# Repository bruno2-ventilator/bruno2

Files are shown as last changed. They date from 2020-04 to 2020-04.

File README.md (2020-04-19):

# BrunO2 Open Source Ventilator
This repository contains design information for a low cost ventilator designed by a team based at Brown University. We are a group of engineers, medical practitioners, and device designers developing a ventilator system based around custom proportional valves, MEMS pressure sensors, and closed-loop control system.

More details and videos are available on the [BrunO2 website](https://sites.brown.edu/bruno2/).

---
## License
These open source ventilator design materials are provided under the conditions specified in the [Permissive License](Permissive%20License--Brown%20University%20041720.pdf)

---
## Quick Links:
[System](Design%20Materials/System/)   /   [Mechanical](Design%20Materials/Mechanical/)   /   [Software](Design%20Materials/Software/)   /   [Electronics](Design%20Materials/Electronics/)   /   [BrunO2 website](https://sites.brown.edu/bruno2/).

---
## Getting Started:

COMING SOON

---
# Contributors to the BrunO2 project include:

**Brown University School of Engineering:**
- Prof. Dan Harris (Fluids)
- Prof. Roberto Zenit (Fluids)
- Prof. Kenny Breuer (Fluids)
- Prof. Jacob Rosenstein (ECE)
- Chris Bull (Director of BDW)
- Ben Lyons (BDW Staff)
- Garam Lee (MechE)
- Ian Ho (MechE)
- John Antolik (MechE)
- Will Haddock (MechE)
- Jacob Morse (MechE)
- Alberto Bortoni (ECE)
- Marc Powell (BME)
- Eli Silver (MechE)
- Chris Arcadia (ECE)

**Medical team and advisors:**
- Farah L Laiwalla MD/PhD, Prof, Brown BME
- Dan Dworkis, MD/PhD., Asst. Prof. Emergency Medicine, Keck School of Medicine of USC
- Gerardo P. Carino MD/PhD., Associate Professor of Medicine (Clinical), ICU Director, The Miriam Hospital
- Nicole Thomasian, Brown med student
- Roja Garimella, Brown med student
- Anastassia Gorvitovskaia, Brown med student

**Practicing Engineers:**
- Dave Durfee (Bay Computer Associates, Inc.)
- Andy Leonczyk (Ximedica)

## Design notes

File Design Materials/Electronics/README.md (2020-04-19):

# BrunO2 Ventilator Electronic Hardware Components

---
These open source ventilator design materials are provided under the conditions specified in the [Permissive License](../../Permissive%20License--Brown%20University%20041720.pdf)

---
# MORE DETAILS COMING SOON

---
# BrunO2 PCB v1
## 

[PDF Schematic](PCB_v1/BrunO2%20PCB%20Schematic%20v1.pdf)

[Eagle Schematic](PCB_v1/BrunO2_ControlBoard_v1.sch)

[Eagle Layout](PCB_v1/BrunO2_ControlBoard_v1.brd)

[Gerber Files](PCB_v1/BrunO2_ControlBoard_v1_Gerbers_2020-04-05.zip)

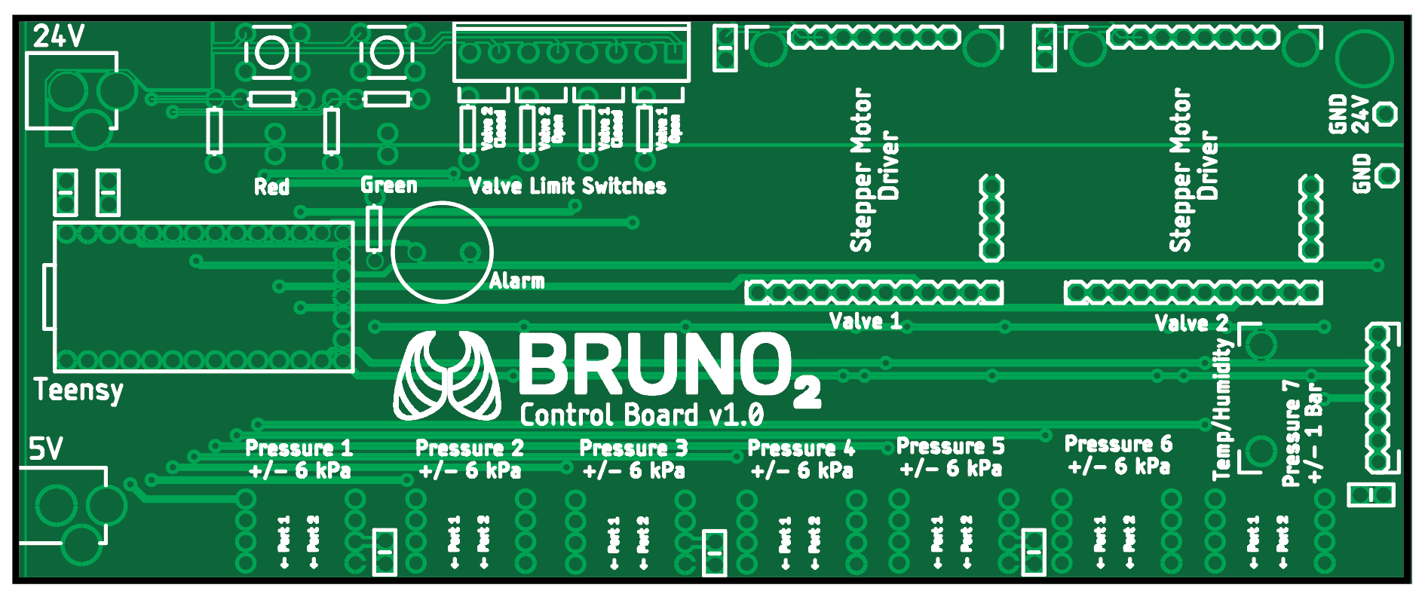
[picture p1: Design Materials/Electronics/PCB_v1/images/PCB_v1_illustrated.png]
PCB Illustration


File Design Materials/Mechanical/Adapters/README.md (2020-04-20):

# BrunO2 Cam Pinch Valve Design Materials

Please refer to [Adapter_Documentation.pdf](Adapter_Documentation.pdf)

This documents is a compilation of the 3D models of generic tube adapters and fittings we made for testing purposes. They were designed to be printed on a high resolution stereolithography 3D printer using biocompatible resin (Form Lab’s ‘Surgical Guide’ resin). All models included in this document have been shared in STL and STEP formats.

## License
These open source ventilator design materials are provided under the conditions specified in the [Permissive License](https://github.com/bruno2-ventilator/bruno2/blob/master/Permissive%20License--Brown%20University%20041720.pdf)

---
# MORE DETAILS COMING SOON

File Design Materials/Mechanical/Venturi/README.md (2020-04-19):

---
## Venturi Design

Please refer to [Venturi_Design_Documentation.pdf](Venturi_Design_Documentation.pdf)

---
## License
These open source ventilator design materials are provided under the conditions specified in the [Permissive License](https://github.com/bruno2-ventilator/bruno2/blob/master/Permissive%20License--Brown%20University%20041720.pdf)

---

This venturi flow sensor was designed to measure the flow rate of an air-oxygen mixture in a rapidly manufacturable ventilator produced at Brown University. It is designed to be printed on a high resolution 3D printer out of biocompatible, autoclavable medium, like Form Lab’s ‘Surgical Guide’ resin. The venturi has barbs on its inlet and outlet so that it can be placed inline with 3/4" ID tygon tubing. The device is modeled in inches.

In the ventilator, this device is paired with a differential pressure sensor: Honeywell 060MDSA-3.

Specs of venturi:

beta (diameter ratio): 0.3
C_0 (discharge coefficient): 0.6
inlet area (inches): 0.625
throat area (inches): 0.118
pressure tap tubing size ID (inches): 1/16 
inlet/outlet tubing size ID (inches): 3/4 

Data for pressure [Pa] vs. flowrate [L/s] curve:

Pressure [Pa]:

    0
    23
    67
    127
    217
    335
    478
    653
    874
    1151
    1458
    1823
    2213

Flow Rate [L/s]:

    0.000
    0.066
    0.112
    0.155
    0.202
    0.251
    0.300
    0.351
    0.406
    0.466
    0.525
    0.587
    0.646

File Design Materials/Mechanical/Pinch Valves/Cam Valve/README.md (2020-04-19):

# BrunO2 Cam Pinch Valve Design Materials

Please refer to [Cam_Valve_Documentation.pdf](Cam_Valve_Documentation.pdf)

This is an electrically-controlled proportional valve driven by a NEMA 17 stepper motor.  It is a "pinch valve" meaning that the fluid only ever touches the inside of the tubing and flow is restricted by pinching the tubing.  This design pinches the tubing with a roller cam attached to the shaft of the stepper motor.  All components are either 3D printed or common fasteners. The pdf documentation contains further details and flow rate data. Sample Arduino codes are included for controlling the valve with some common stepper drivers.

## License
These open source ventilator design materials are provided under the conditions specified in the [Permissive License](https://github.com/bruno2-ventilator/bruno2/blob/master/Permissive%20License--Brown%20University%20041720.pdf)

---
# MORE DETAILS COMING SOON

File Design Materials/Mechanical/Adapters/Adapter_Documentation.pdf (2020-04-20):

Adapters and Fittings

## Introduction

This documents delineates the 3D models of generic tube adapters and fittings we made for testing purposes. They were designed to be printed on a high resolution stereolithography 3D printer using biocompatible resin (Form Lab’s ‘Surgical Guide’ resin). All models included in this document have been shared in STL and STEP formats.

## List of adapters

1. 1/4 NPT to 1/4-inch barb: Connects 1/4-inch ID tubing to ports with female 1/4 NPT threading.

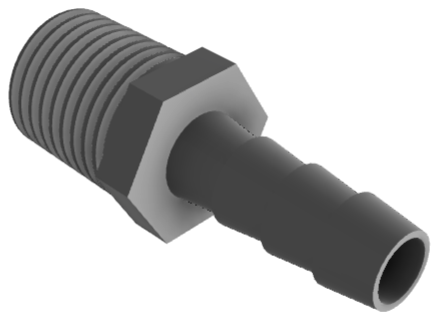
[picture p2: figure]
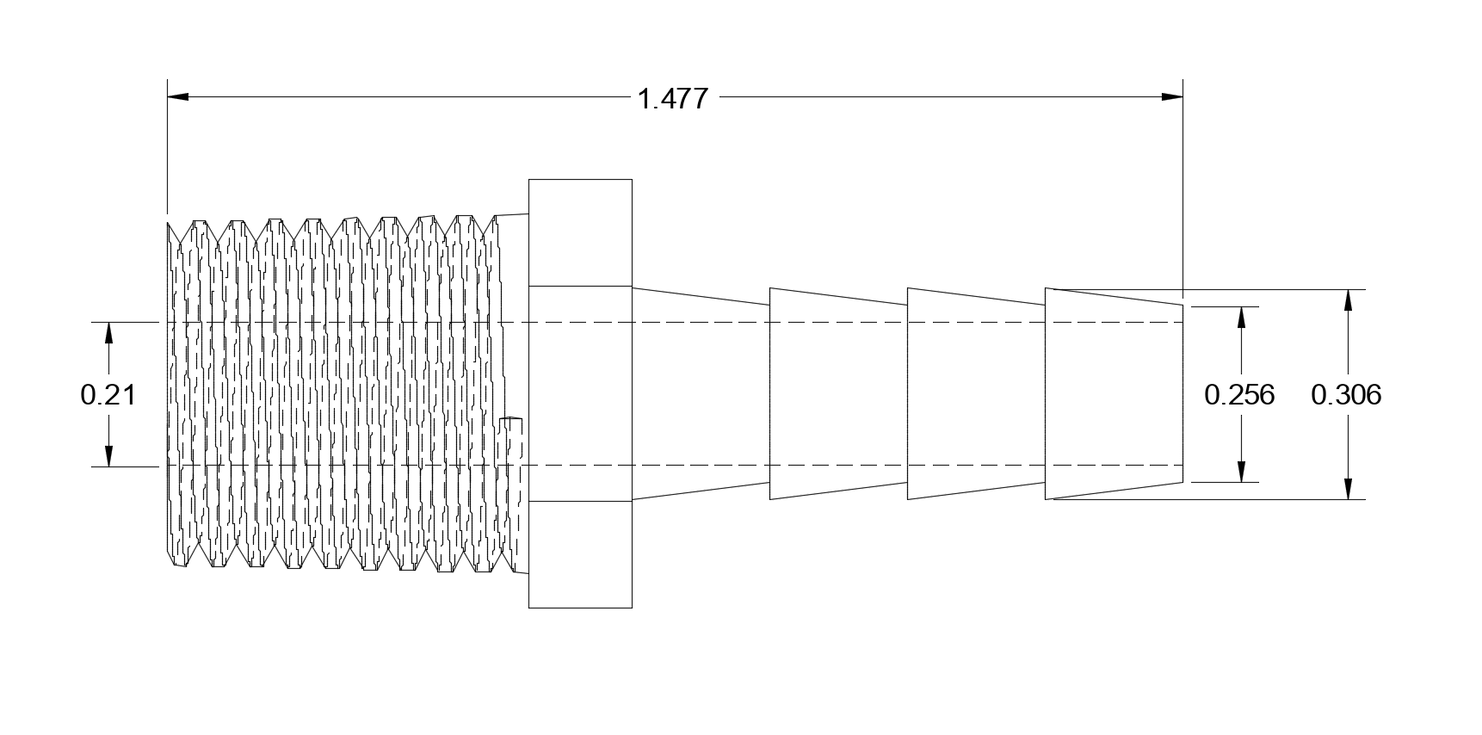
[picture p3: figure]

2. 1/4 NPT to 3/4-inch barb: Connects 3/4-inch ID tubing to ports with female 1/4 NPT threading.

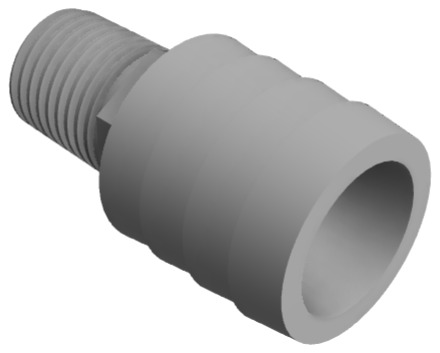
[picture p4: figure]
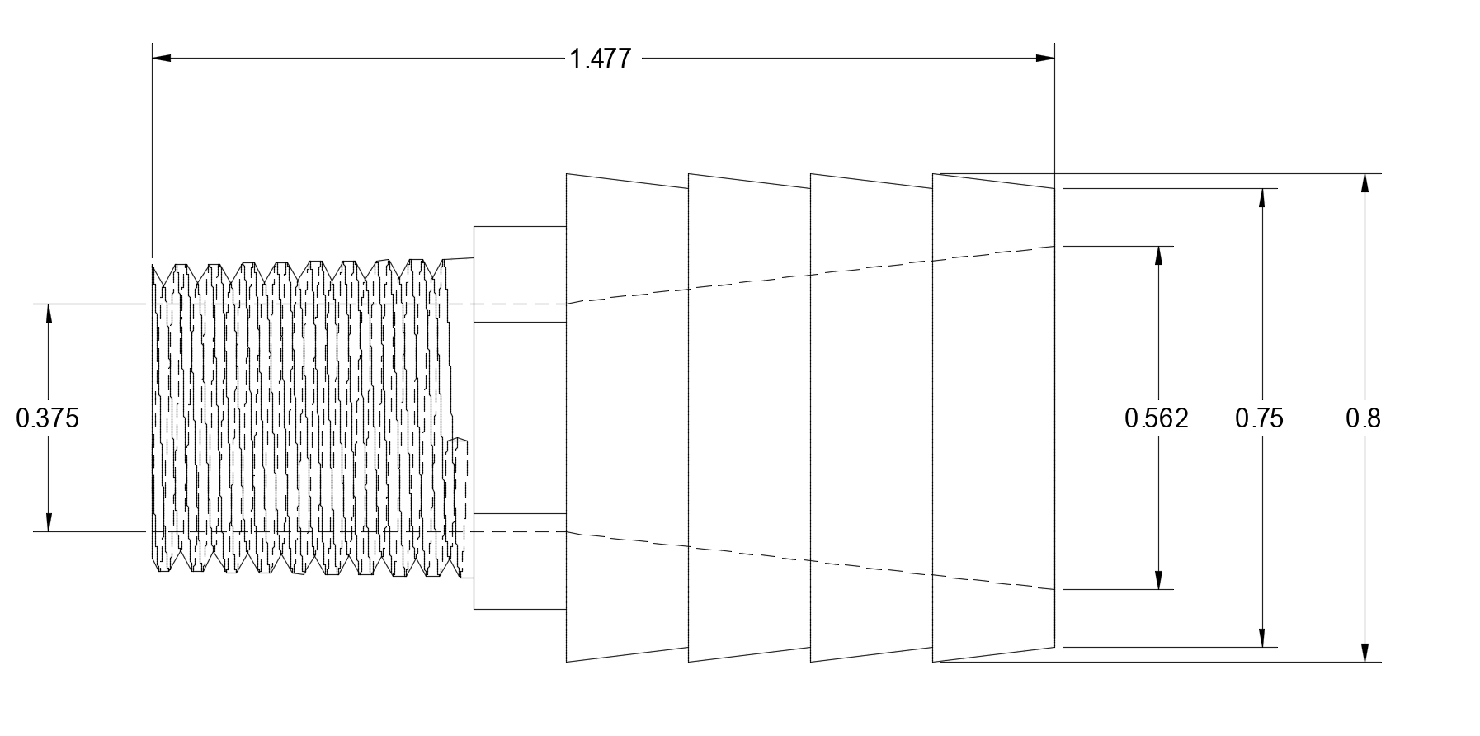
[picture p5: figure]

Adapters and Fittings

3. 3/4-inch barb to 1/4-inch barb: Connects 1/4-inch ID tubing to 3/4-inch ID tubing.

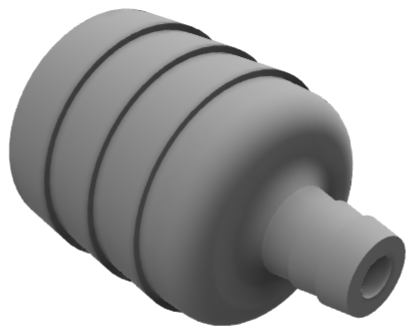
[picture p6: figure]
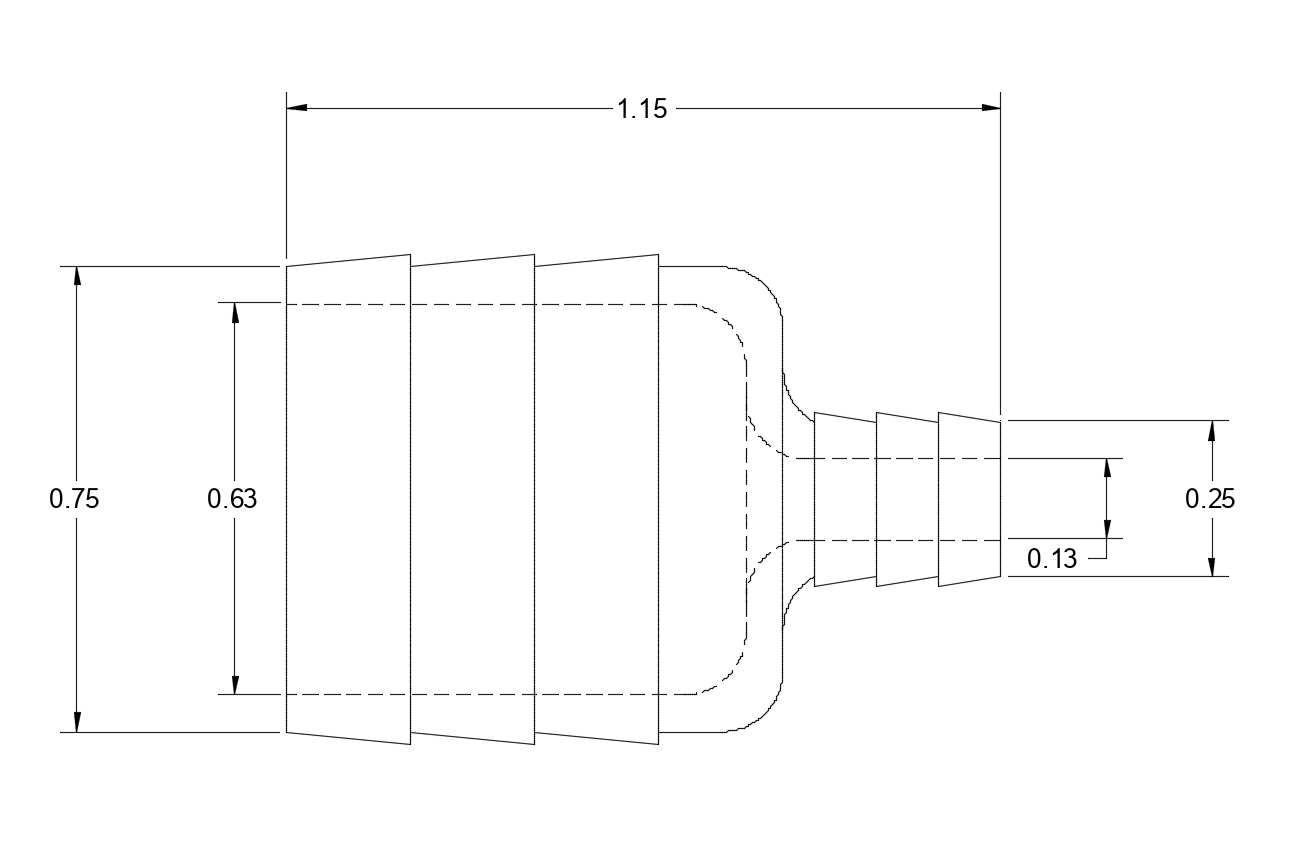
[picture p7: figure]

4. 3/4-inch barb to 3/4-inch barb: Connects 3/4-inch ID tubing to 3/4-inch ID tubing.

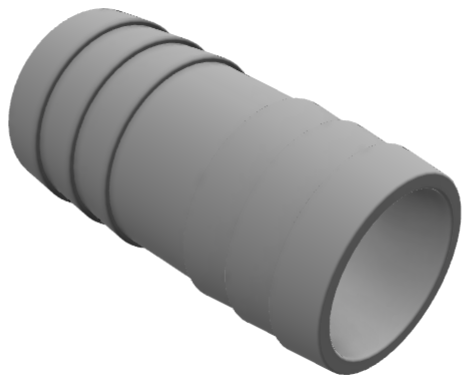
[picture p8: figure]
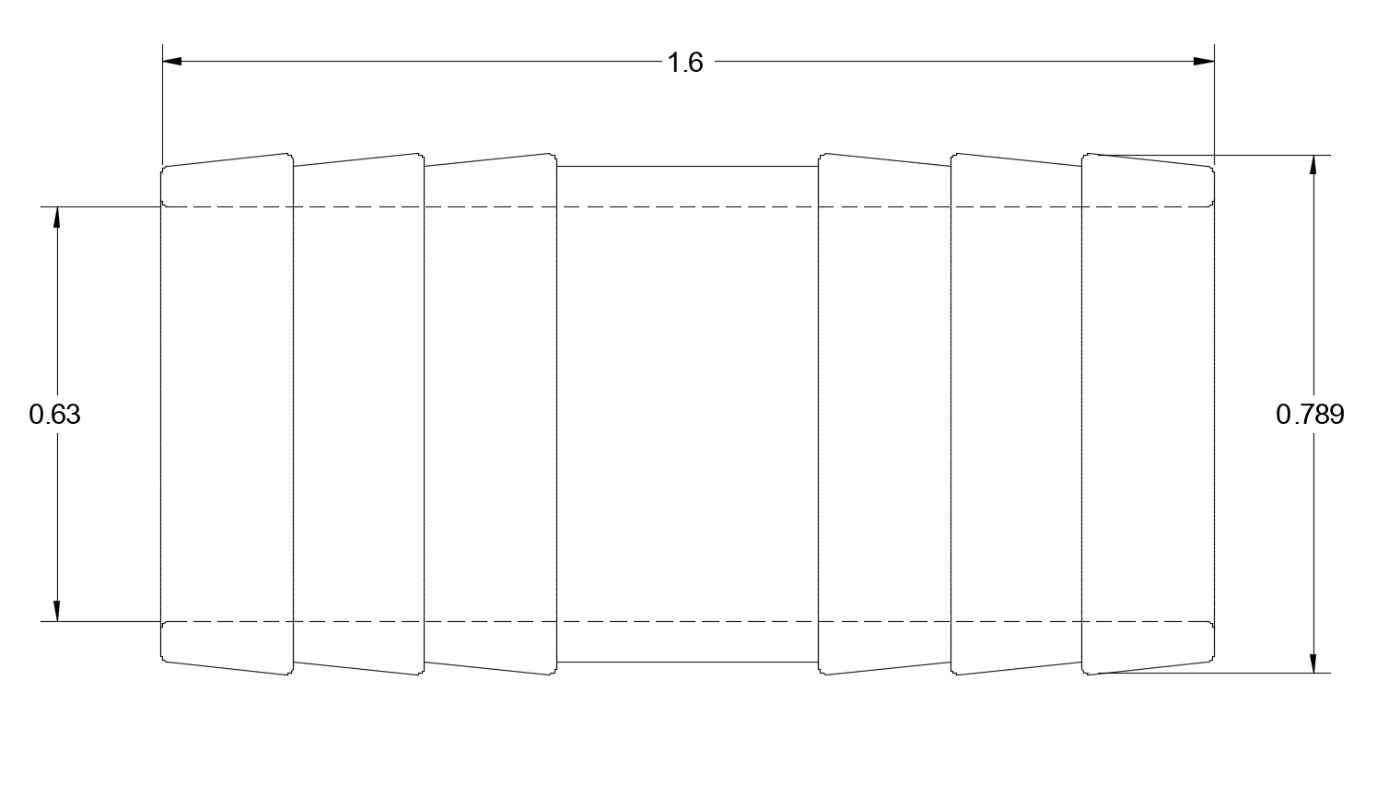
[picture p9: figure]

Adapters and Fittings

5. 3/4-inch barb to 22mm connector: Connects 3/4-inch ID tubing to 22mm ID tubing. The right port has an OD of 22mm and ID of 19mm. This should fit with most CPAP tubing.

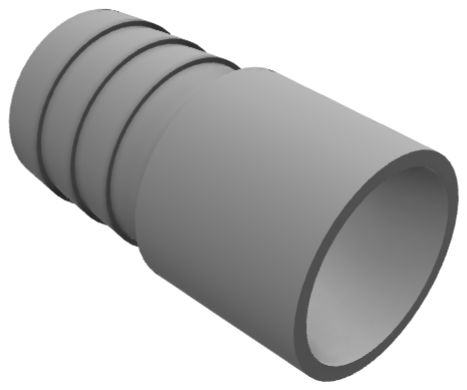
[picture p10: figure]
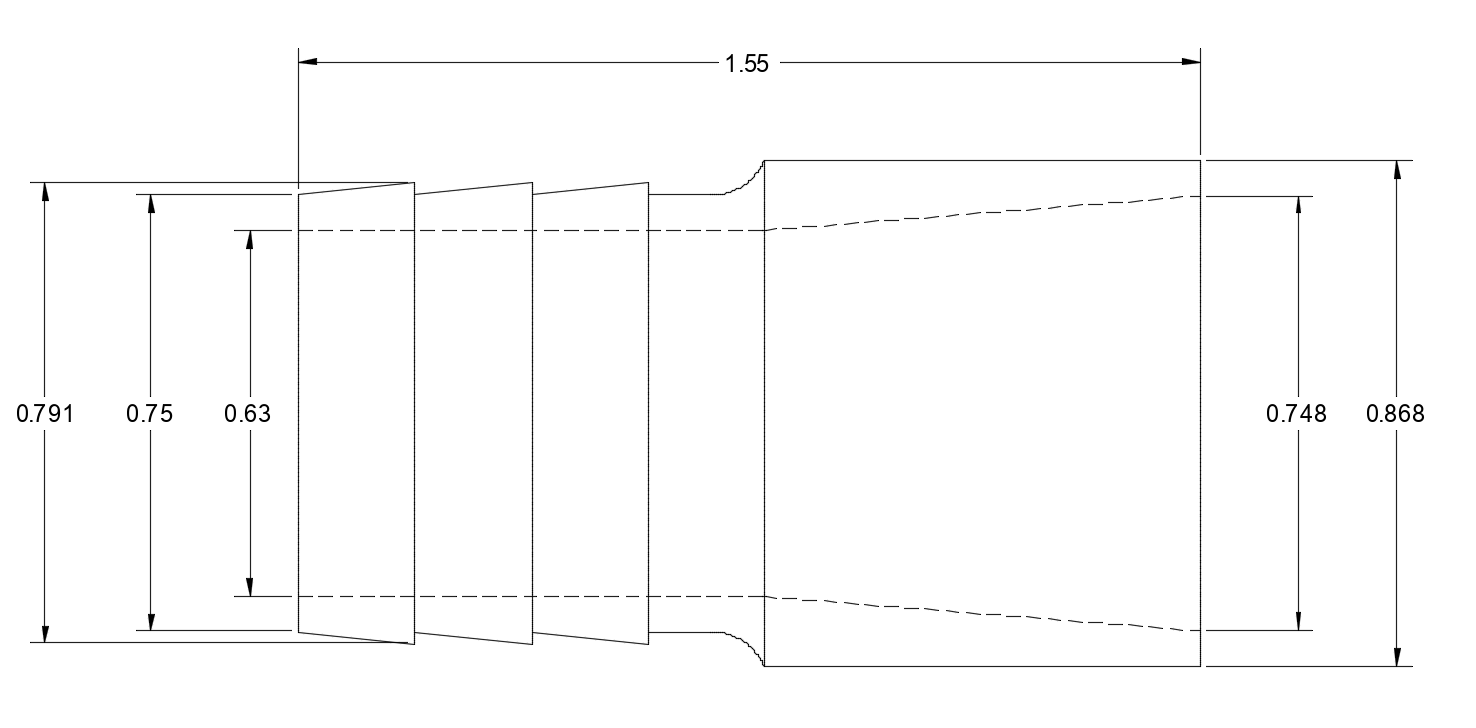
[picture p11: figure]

6. Pressure tap, 3/4-inch barb : Connects our pressure sensor inline to 3/4-inch ID tubing.

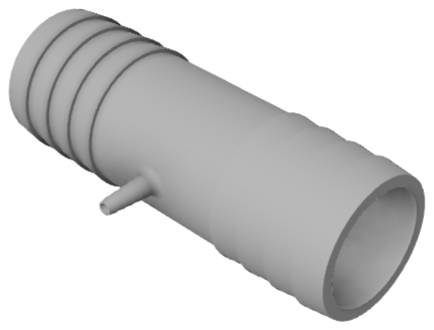
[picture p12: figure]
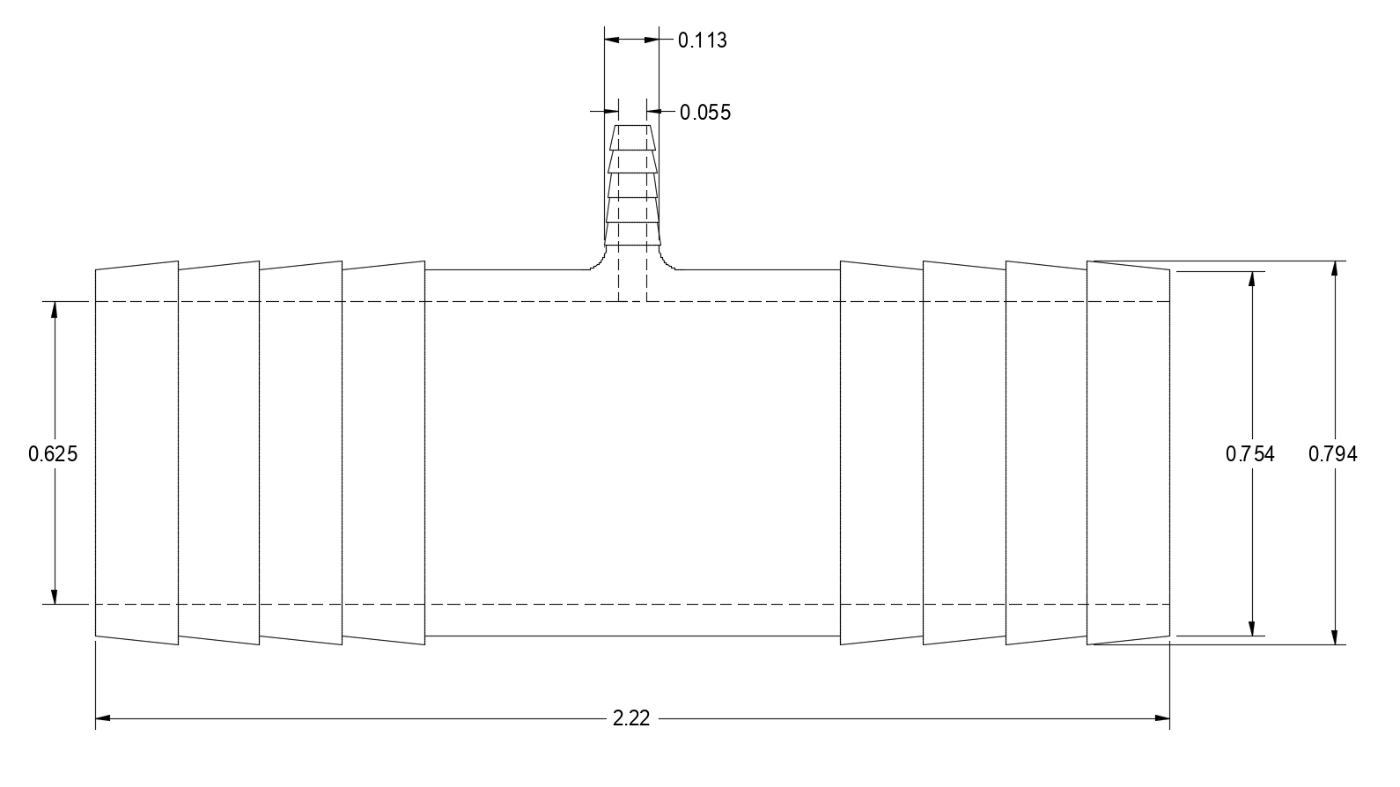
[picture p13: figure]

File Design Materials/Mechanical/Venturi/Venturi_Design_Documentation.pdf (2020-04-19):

Venturi Flow Sensor Design Documentation

## Introduction

This venturi flow sensor was designed to measure the flow rate of an air-oxygen mixture in a rapidly manufacturable ventilator produced at Brown University. It is designed to be printed on a high resolution 3D printer out of biocompatible, autoclavable medium, like Form Lab’s ‘Surgical Guide’ resin. The venturi has barbs on its inlet and outlet so that it can be placed inline with 3
4

inch ID Tygon tubing. A pressure differential is generated across the two barbed pressure taps on the top of the device, which is proportional to the flow rate through the venturi:

Q =

C0A0
ρ

p
1 − β

4

√
2∆P

where Q is the flow rate through the device, P is the pressure differential between the ports, C0 is the discharge coefficient of the venturi, A0 is the throat area, ρ is the mass density of the airflow, and β is the ratio of inlet ID to throat ID. Figure 1 shows a technical schematic of the venturi.

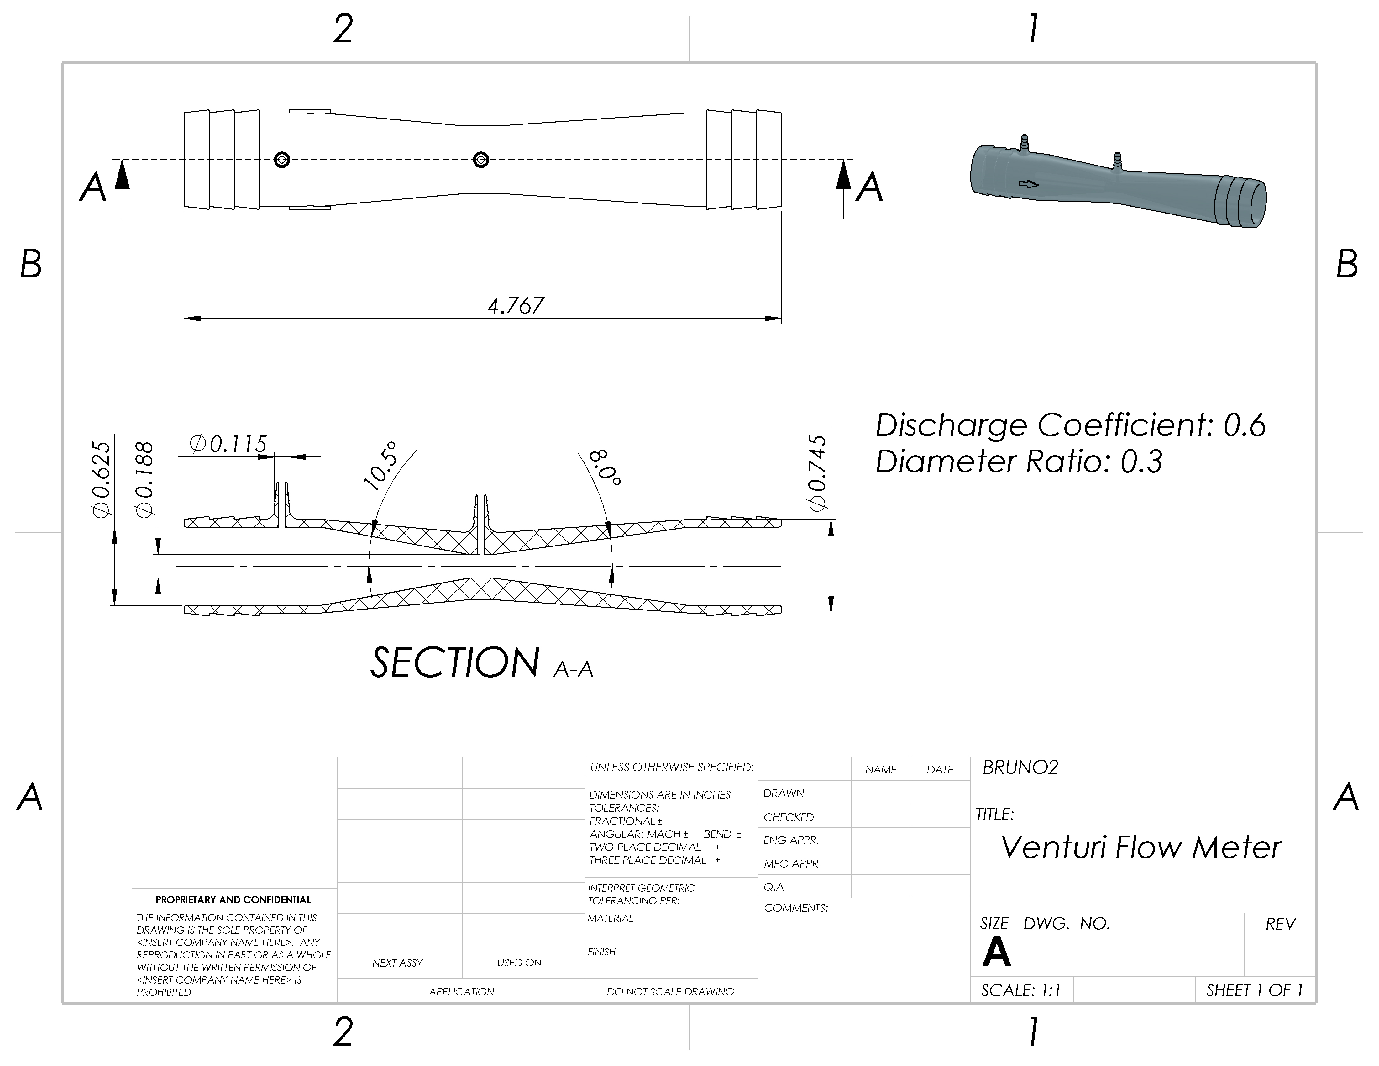
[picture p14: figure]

Figure 1: schematic of venturi flow meter

## Design Process

The main considerations for the design of this sensor was the pressure differential that would be created in the relevant flow rate range of the system, which in the case of the ventilator is 0 - 1.5 LPS. It was found that 6 kPa differential pressure sensors could be used elsewhere in the system for absolute line pressure measurements, so this venturi is designed to not exceed 6 kPa at 1.5 LPS of flow. The pressure differential

Venturi Flow Sensor Design Documentation

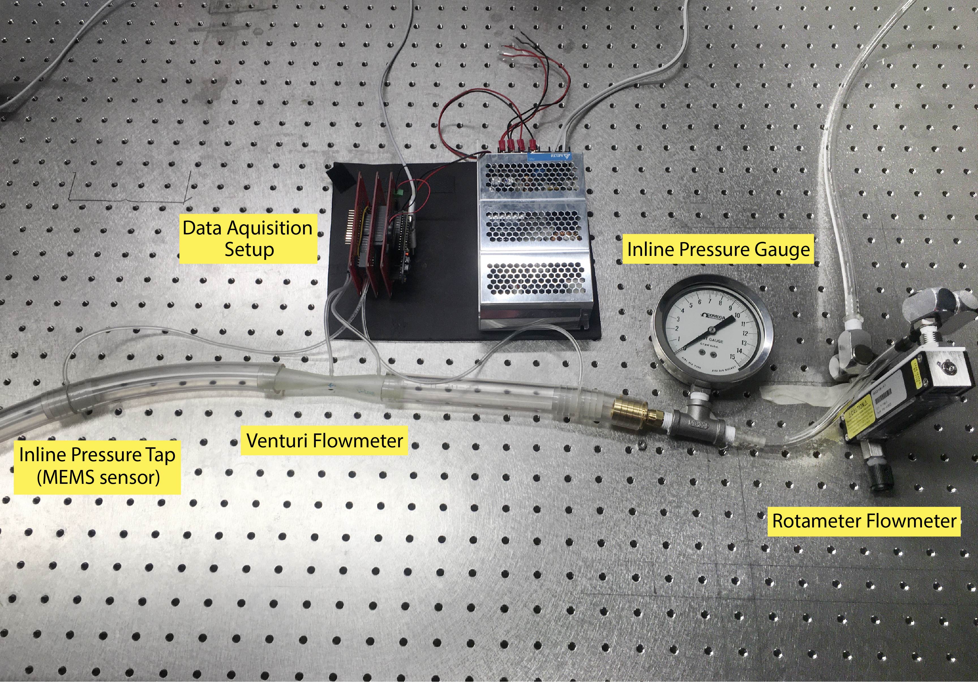
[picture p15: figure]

Figure 2: test set up for determining venturi dischrage coefficient

Venturi Flow Sensor Design Documentation

that is developed is related to the flow rate, density of the gas, and the geometry of the venturi. The diameter ratio β (the ratio between the inlet ID and the throat ID) has a large effect of the pressure differential that is developed, and could be tuned if another pressure range was desired. It is worth noting that reducing β below 0.2 will cause high head losses over the sensor, which is not desirable. To mitigate head loss over the sensor, shallower contraction and expansion angles were adopted over the course of the development of this sensor. We found that reducing the angle of the expansion angle from 15 degrees to 8 degrees had a large effect on the head loss of the sensor.

## Testing

The discharge coefficient, C0, was determined experimentally using a rotameter flow meter as a calibration instrument (Cole Parmer item #: 03218-41). High pressure air from a compressor was regulated down to 25 PSI and passed through the rotameter, which throttled the flow rate down to a range of 0 - 58.5 LPM with an accuracy of ± 1.17 LPM. Flow through the rotameter was correlated to a pressure differential between the venturi ports for increments of 5 LPM between 0 and 58.5 LPM. The parameter C0 was adjusted from a theoretical value of 0.9 to 0.6 in the governing equation to fit the results of the calibration study. An image of the experimental set up is shown in figure 2, and the pressure differential - flow rate curves are shown in figure 3.

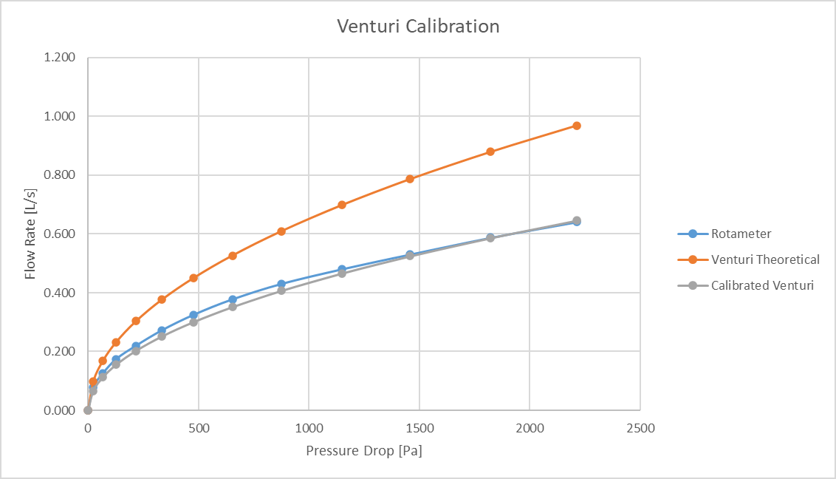
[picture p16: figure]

Figure 3: plot of flow rate vs pressure differential, used to calibrate the venturi flow sensor

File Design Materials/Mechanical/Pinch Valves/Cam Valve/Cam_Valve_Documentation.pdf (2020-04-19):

Cam Pinch Valve Documentation

This proportional pinch valve is designed to be fully 3D printed and utilizes a readily available, inexpensive NEMA 17 stepper motor for mechanical control. The valve has been tested for full closure up to 15psi and can go from fully closed to fully open in 0.03 seconds or faster depending on the quality of the stepper motor. The valve operates by using a a cam to pinch a section of 3/8” OD, 1/4” ID soft tubing and reduce the flow area. This design means that the working fluid only ever contacts the inside of the tubing to mitigate the risk of contamination. The tubing can be easily replaced between patients. Note that the current design uses latex tubing - we are exploring alternative materials so that the ventilator can be used on patients with latex allergies.

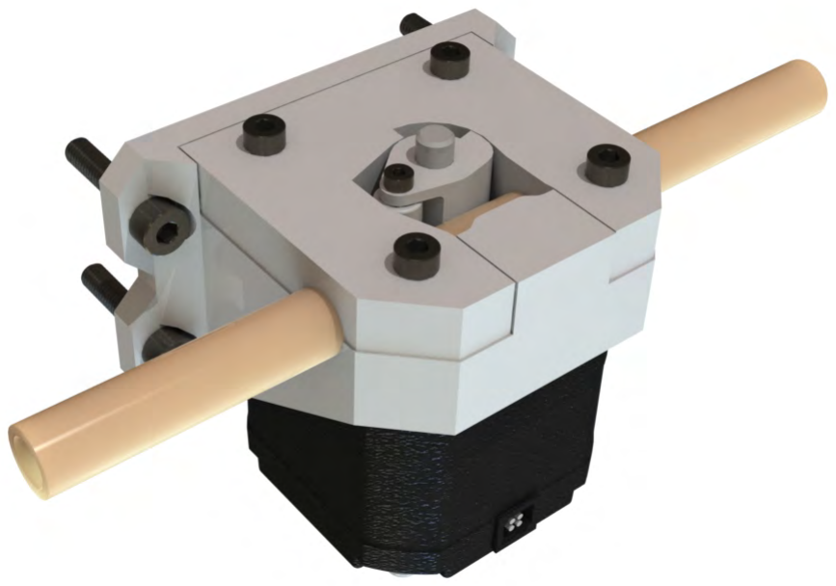
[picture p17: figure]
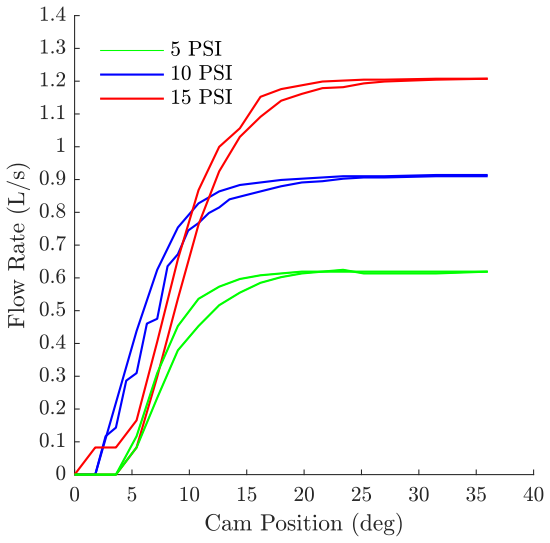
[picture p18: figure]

Flow rate vs. cam position for 5, 10 and 15 PSI pressure drop across the valve. Both opening and closing are shown to demonstrate minimal hysteresis.

## Required Materials

Part | Quantity | Supplier
Housing | 1 | 3D printed
Housing cover | 1 | 3D printed
Cam | 1 | 3D printed
Roller | 1 | 3D printed
M3x22 screw | 4 | McMaster (https://www.mcmaster.com/91290a124)
M2x16 screw | 1 | McMaster (https://www.mcmaster.com/91290a047)
M4x20 screw | 4 | McMaster (https://www.mcmaster.com/91290a168)
M3x4 set screw | 1 | McMaster (https://www.mcmaster.com/91390a098)
NEMA 17 stepper motor | 1 | Adafruit (https://www.adafruit.com/product/324)
3/8OD, 1/4ID soft latex tubing | 6” | McMaster (https://www.mcmaster.com/5234k44-5234K33)
Tool | Use
1.5mm Allen key | Set screw and roller screw
2.5mm Allen key | Housing cover screws
3mm Allen key | Valve mounting screws
5mm or letter F drill | Fit cam to motor shaft
Small wire cutters | Remove supports
Small files and sandpaper | Remove support remnants

## Assembly Instructions

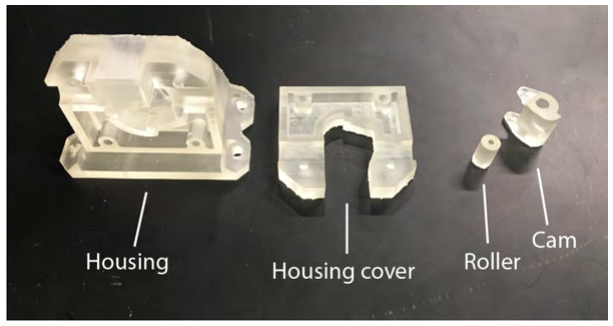
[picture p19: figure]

Four components must be 3D printed for each cam valve. They are the housing, the housing cover, the cam, and the roller. We recommend using a resin 3D printer rather than a filament one due to its higher dimensional accuracy - we printed with a FormLabs Form 2 with clear resin and 0.05mm layer height. Be mindful of reference surfaces when placing supports. We found that it works best to print with the internal features of the housing components facing away from the build platform, so the parts are supported on external features. After the print finishes, remove the supports with small wire clippers and sand and file away the remnants.

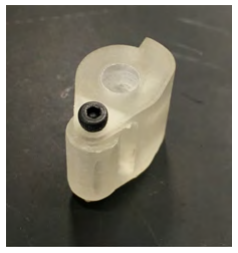
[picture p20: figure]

Begin by assembling the cam and roller using a M2x16 socket head cap screw. One side of the cam is a clearance hole and the other is threaded M2x0.4. After installing the roller, make sure that it spins freely. Don’t over tighten the screw as it will pinch the roller. You may need to work the roller back and forth until it spins freely.

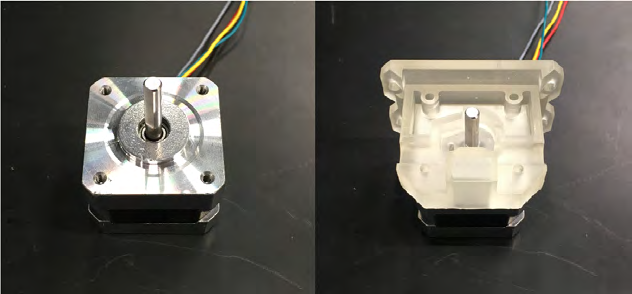
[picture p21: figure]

Place the housing onto the face of the stepper motor. The circular boss on the stepper motor should register in the housing. The motor can be oriented in any direction so pick one based on desired wire routing after the valve is mounted.

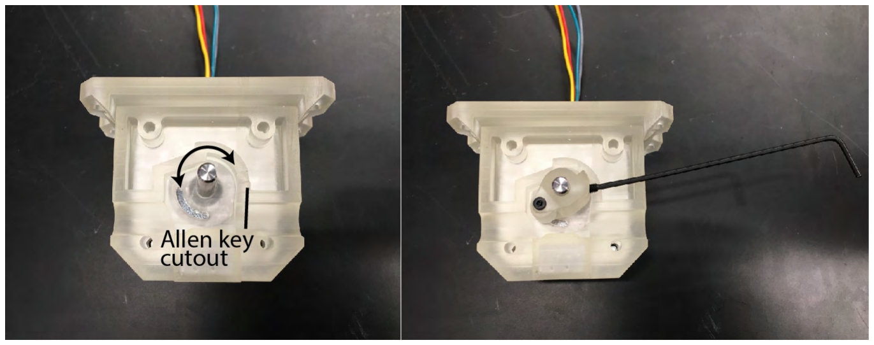
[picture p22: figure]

Turn the motor shaft by hand until the flat points towards the circular cutout in the housing intended for Allen key access. Slip the cam/roller subassembly onto the shaft. You may need to expand the hole in the cam slightly using a 5mm or letter F drill. Use the drill with a hand chuck or by hand, not under power. Use a 1.5mm Allen key to install the M3x4 set screw. Tighten onto the motor shaft.

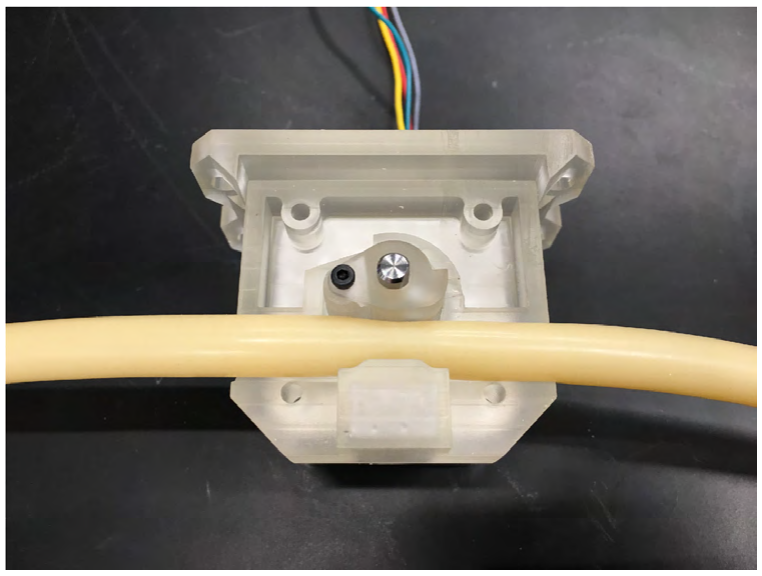
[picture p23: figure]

Turn the cam so that it is out of the way and press the soft latex tubing into the semicircular channel. If you are using a short section of tubing and adapting it to other tubing in the circuit, center the tubing in the housing. This is a good time to make sure that the tolerances on the printed parts are correct. Try turning the cam by hand to pinch the tubing shut. It should not require much force to seal completely. If the force is excessive or the tubing does not appear to be fully compressed, we have included STL files for undersized and oversized rollers.

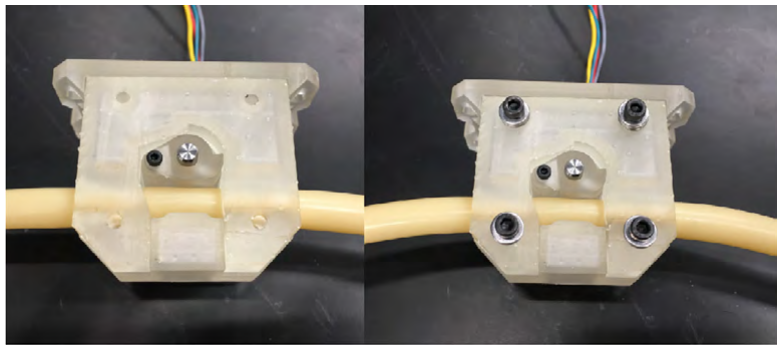
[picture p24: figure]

Place the housing cover onto the housing and ensure that the cam does not bind as a result. The housing cover may need to be sanded if this occurs. Once the fit is good, fasten the housing cover and housing to the stepper motor with M3x22 screws. The housing includes holes for 4 M4 screws which can be used to mount the valve to a device.

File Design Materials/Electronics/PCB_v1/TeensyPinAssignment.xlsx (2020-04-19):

Pin Number | Net Label | Description
0 | RX1
1 | TX1
2 | CS PS1 | Pressure Sensor Chip Select (6 kPa)
3 | CS PS2 | Pressure Sensor Chip Select (6 kPa)
4 | CS PS3 | Pressure Sensor Chip Select (6 kPa)
5 | CS PS4 | Pressure Sensor Chip Select (6 kPa)
6 | CS PS5 | Pressure Sensor Chip Select (6 kPa)
7 | CS PS6 | Pressure Sensor Chip Select (6 kPa)
8 | CS PS7 | Pressure Sensor Chip Select (1 bar)
9 | CS M1 | Motor Driver Chip Select
10 | CS M2 | Motor Driver Chip Select
11 | MOSI | Master Out Slave In (M1, M2, BME280)
12 | MISO | Master In Slave Out (All)
13 | SCK | Serial Clock (All)
14 | Valve1_o | Valve Open Limit Switch
15 | Valve1_c | Valve Closed Limit Switch
16 | Valve2_o | Valve Open Limit Switch
17 | Valve2_c | Valve Closed Limit Switch
18 | SDA
19 | SCL
20 | CS BME280 | Temp/Humidty Sensor Chip Select
21 | LED/Switch 1 | Input Output for LED/Switch
22 | LED/Switch 2 | Input Output for LED/Switch
23 | Buzzer | Mini Speaker PWM Control Pin

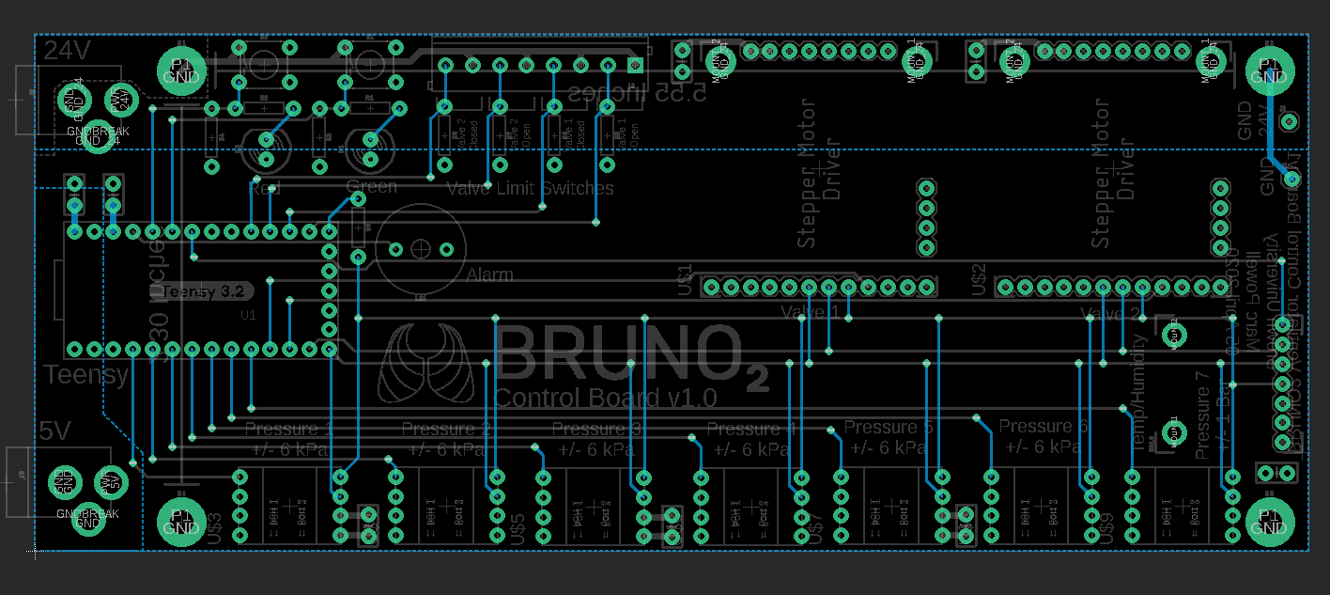
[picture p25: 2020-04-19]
Design Materials/Electronics/PCB_v1/images/Bottom.PNG

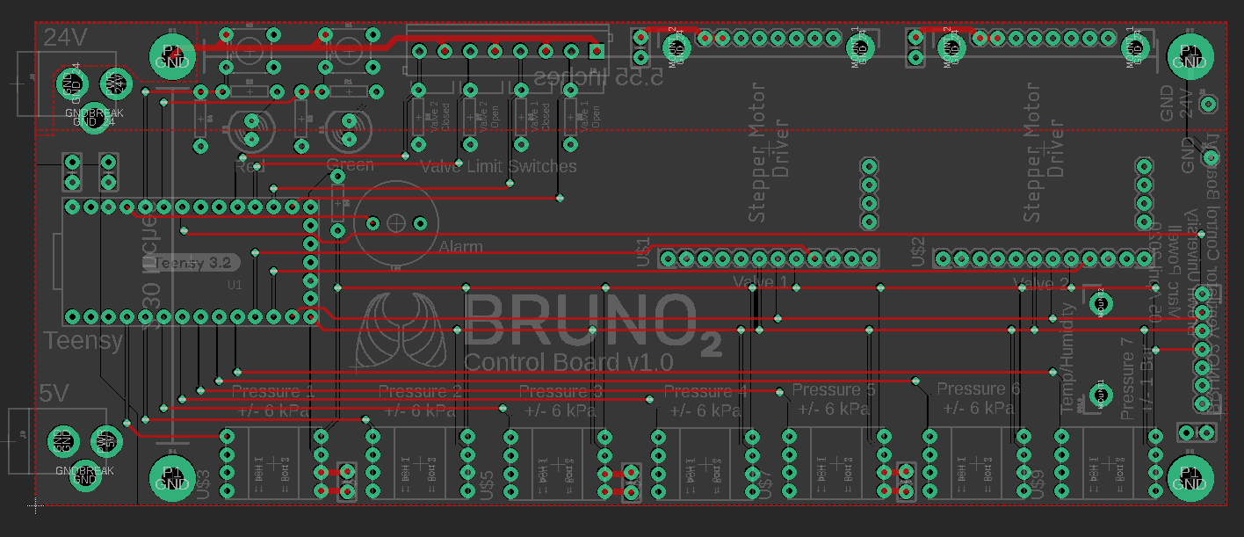
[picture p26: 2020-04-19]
Design Materials/Electronics/PCB_v1/images/Top.PNG

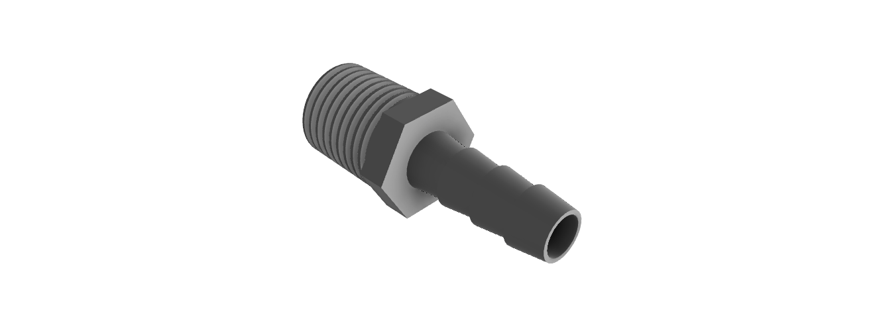
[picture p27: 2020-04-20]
Design Materials/Mechanical/Adapters/1:4 NPT to 1:4-inch barb/1:4 NPT to 1:4-inch barb.png

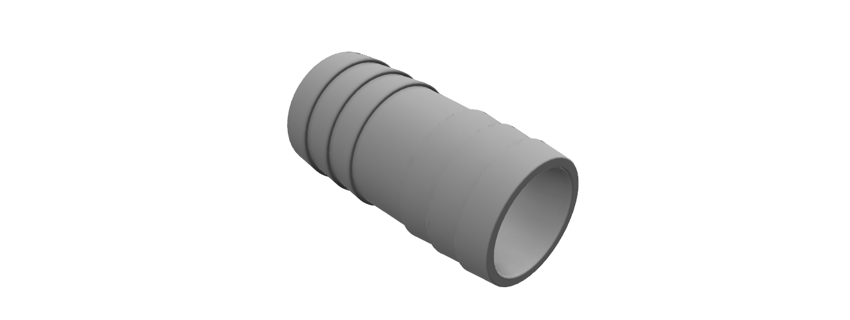
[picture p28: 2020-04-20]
Design Materials/Mechanical/Adapters/3:4-inch barb to 3:4-inch barb/3:4-inch barb to 3:4-inch barb.png

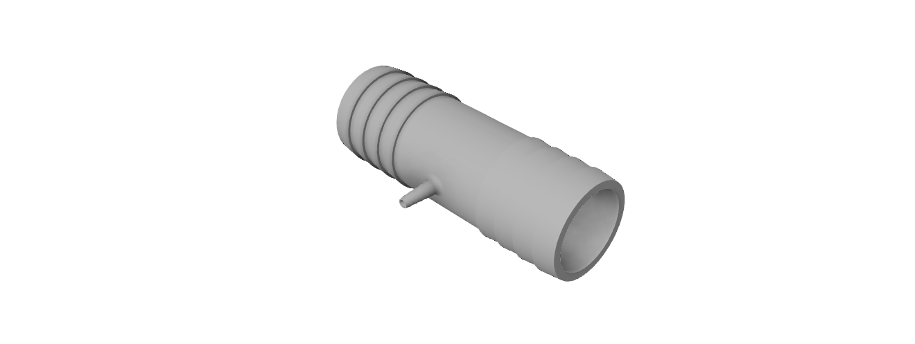
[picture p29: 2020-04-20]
Design Materials/Mechanical/Adapters/Pressure tap, 3:4-inch barb /Pressure tap, 3:4-inch barb.png

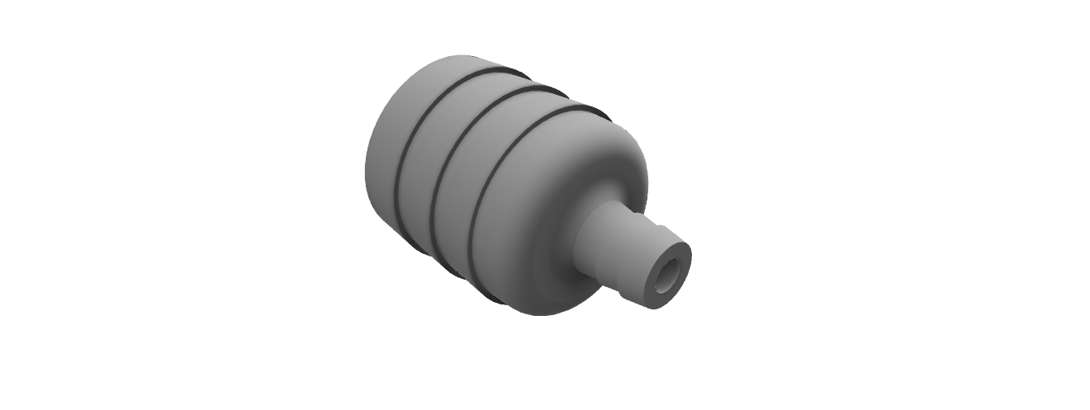
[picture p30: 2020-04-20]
Design Materials/Mechanical/Adapters/3:4-inch barb to 1:4-inch barb/3:4-inch barb to 1:4-inch barb.png

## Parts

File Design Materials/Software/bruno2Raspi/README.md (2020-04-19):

# BrunO2 Software: Graphical User Interface

For a system-level diagram, please refer to the [System README page](../../System/README.md).

---
These open source ventilator design materials are provided under the conditions specified in the [Permissive License](../../Permissive%20License--Brown%20University%20041720.pdf)

---
# MORE DETAILS COMING SOON

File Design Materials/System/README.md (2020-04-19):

# BrunO2 Ventilator System Design

---
These open source ventilator design materials are provided under the conditions specified in the [Permissive License](../../Permissive%20License--Brown%20University%20041720.pdf)

---
# Mechanical System Overview

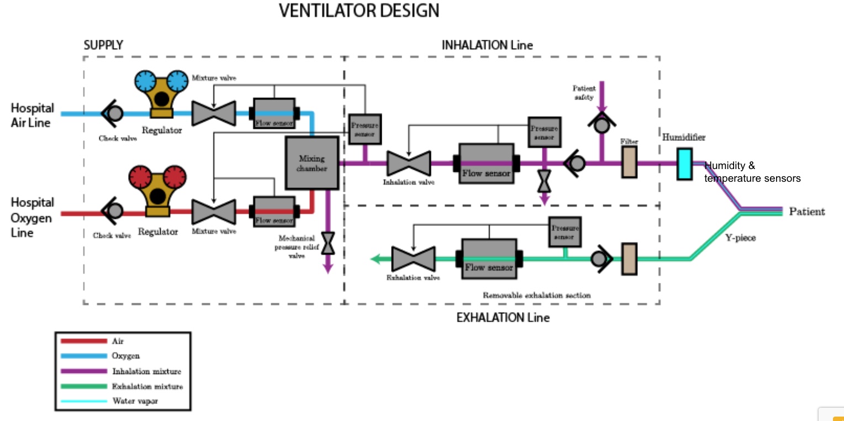
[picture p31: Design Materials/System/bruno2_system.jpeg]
system


---
# Electronic Control System Overview

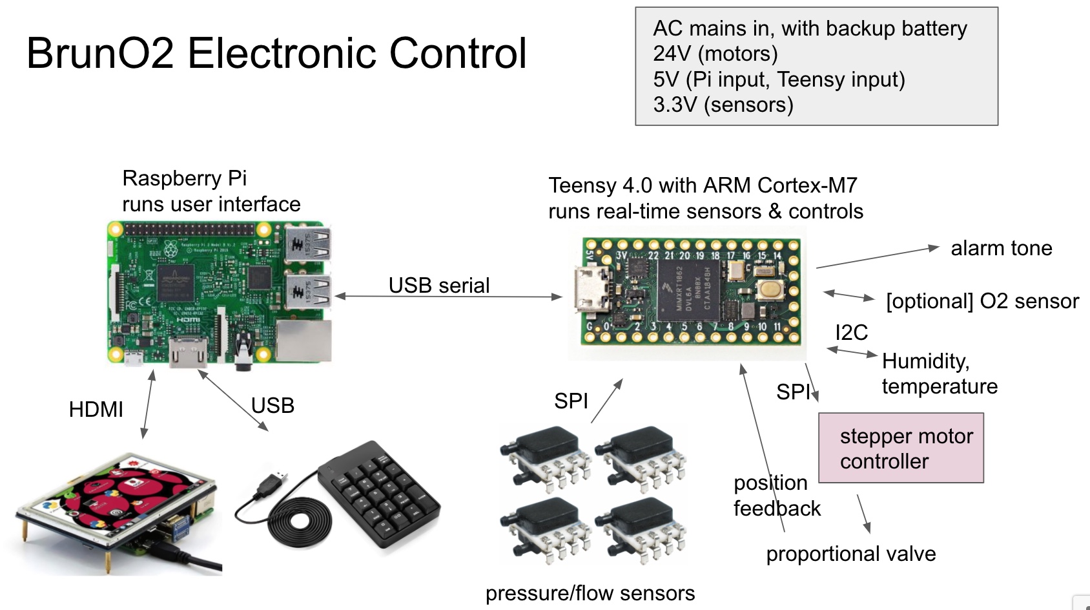
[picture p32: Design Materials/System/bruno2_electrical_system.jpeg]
system


---
# MORE DETAILS COMING SOON

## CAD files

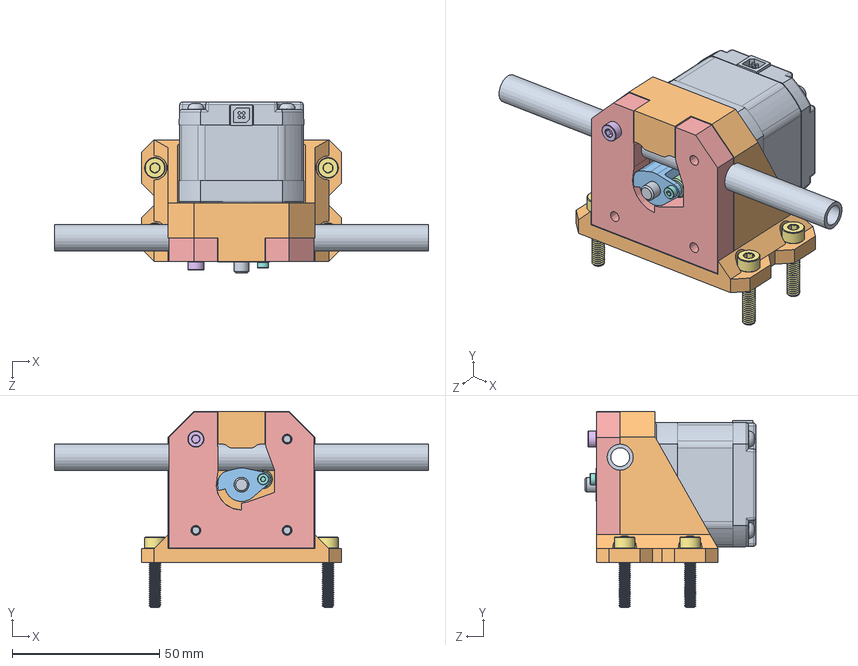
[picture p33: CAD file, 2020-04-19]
Design Materials/Mechanical/Pinch Valves/Cam Valve/SLDPRT/Peristlatic Valve 0.375.SLDASM
127.0 x 66.6 x 58.2 mm
NEMA 17 Stepper
Housing
Cam
Roller 0.375
Top
M4x20SHCP x 4
M2x16 SHCP
0.375 Tubing

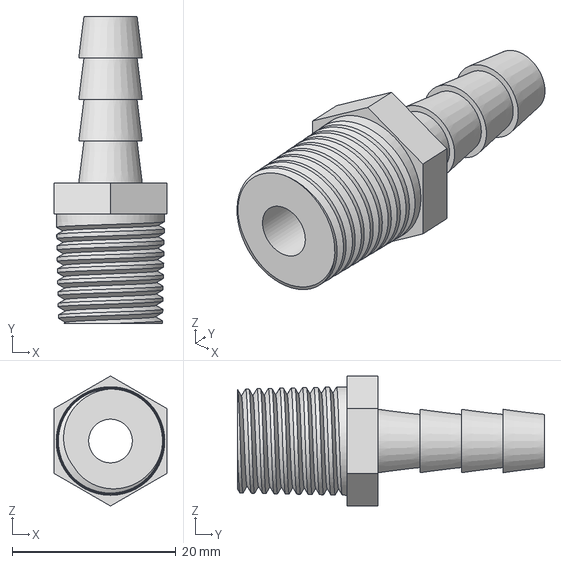
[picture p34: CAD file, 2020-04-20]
Design Materials/Mechanical/Adapters/1:4 NPT to 1:4-inch barb/1:4 NPT to 1:4-inch barb.step
13.7 x 37.5 x 15.9 mm

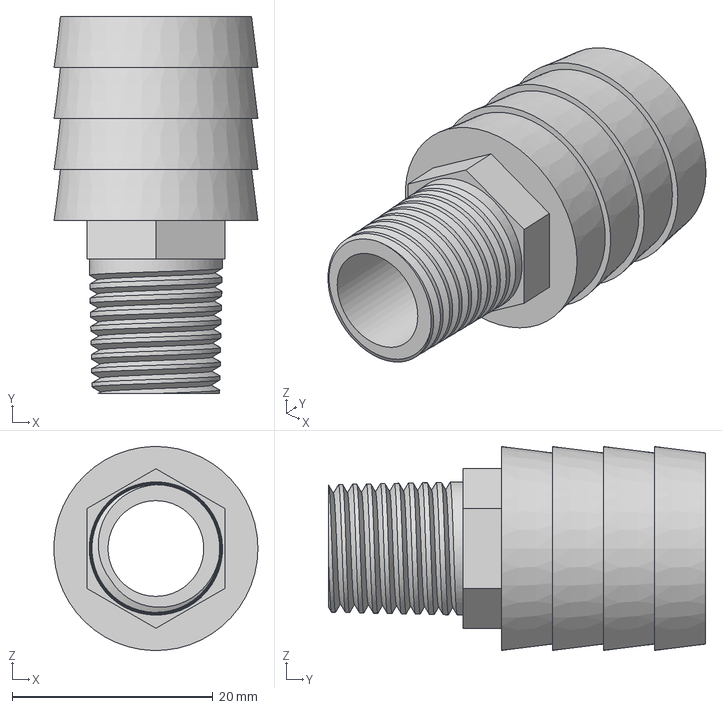
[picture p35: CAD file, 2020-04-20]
Design Materials/Mechanical/Adapters/1:4 NPT to 3:4-inch barb/1:4 NPT to 3:4-inch barb.step
20.3 x 37.5 x 20.3 mm

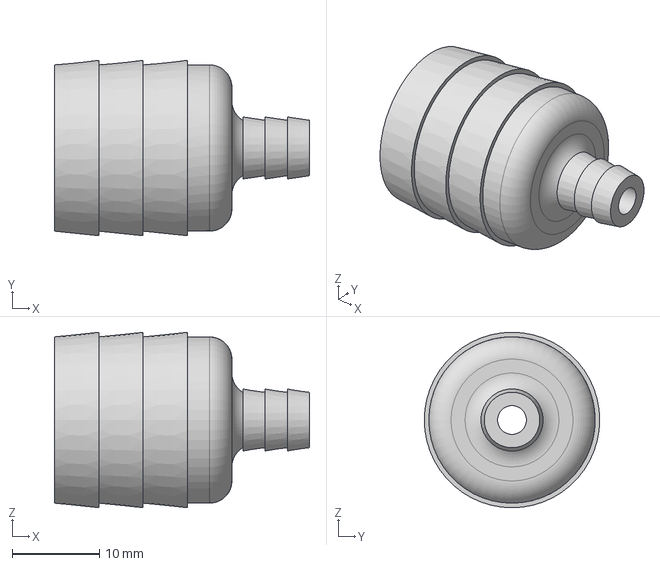
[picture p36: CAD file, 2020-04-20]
Design Materials/Mechanical/Adapters/3:4-inch barb to 1:4-inch barb/3:4-inch barb to 1:4-inch barb.step
29.2 x 20.1 x 20.1 mm

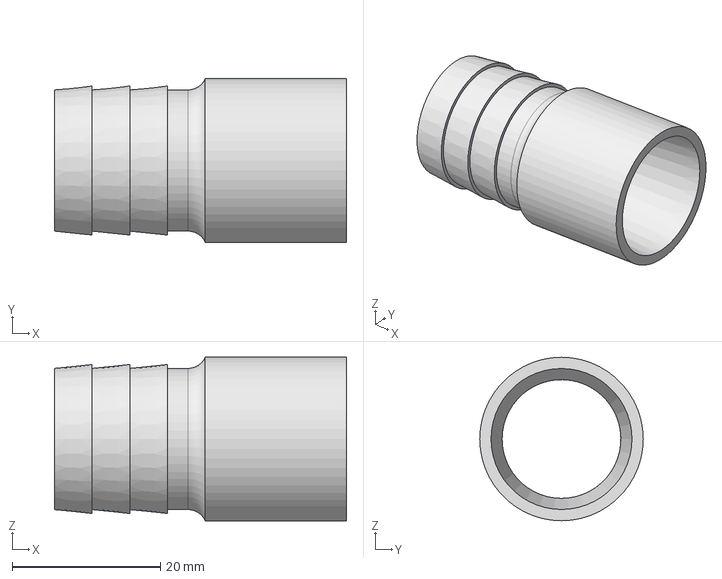
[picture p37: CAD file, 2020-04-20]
Design Materials/Mechanical/Adapters/3:4-inch barb to 22mm/3:4-inch barb to 22mm.step
39.4 x 22.1 x 22.1 mm

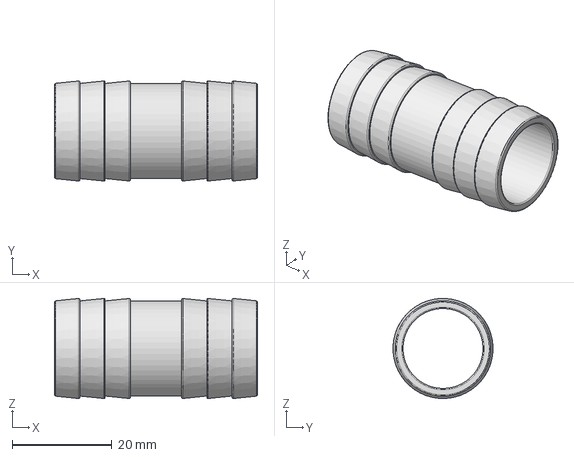
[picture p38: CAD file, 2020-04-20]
Design Materials/Mechanical/Adapters/3:4-inch barb to 3:4-inch barb/3:4-inch barb to 3:4-inch barb.step
40.6 x 20.0 x 20.0 mm

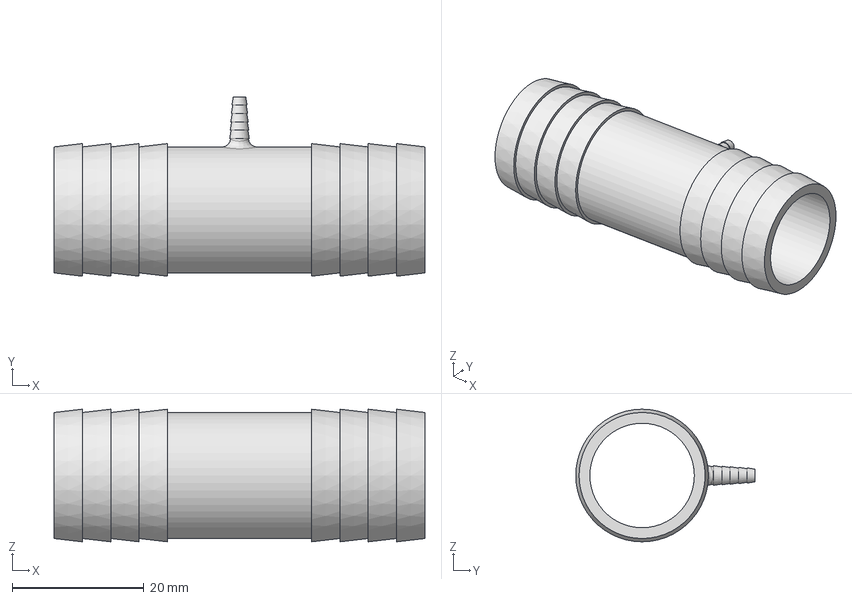
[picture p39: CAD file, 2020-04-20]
Design Materials/Mechanical/Adapters/Pressure tap, 3:4-inch barb /Pressure tap, 3:4-inch barb.step
56.4 x 27.3 x 20.2 mm

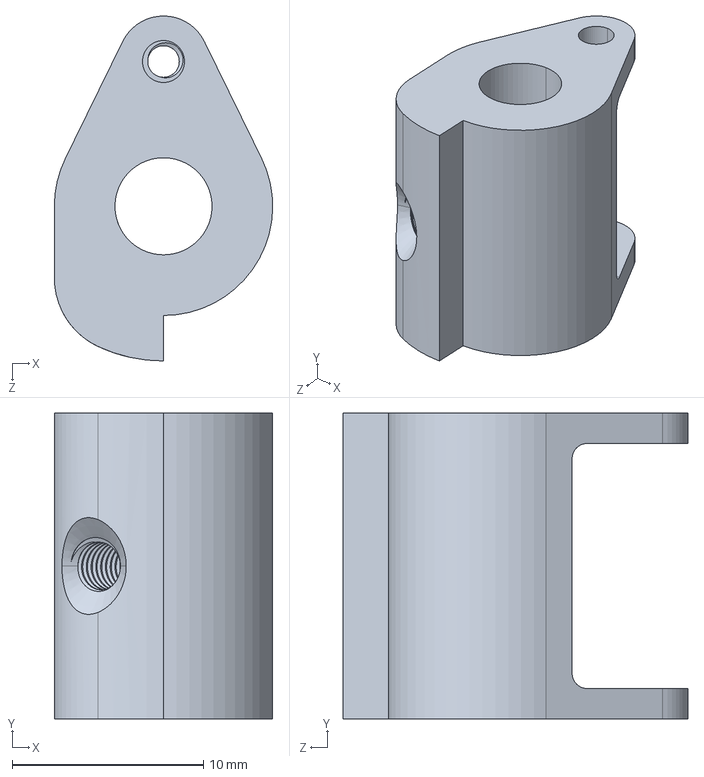
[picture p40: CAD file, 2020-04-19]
Design Materials/Mechanical/Pinch Valves/Cam Valve/STEP/Cam.STEP
11.4 x 16.0 x 18.1 mm

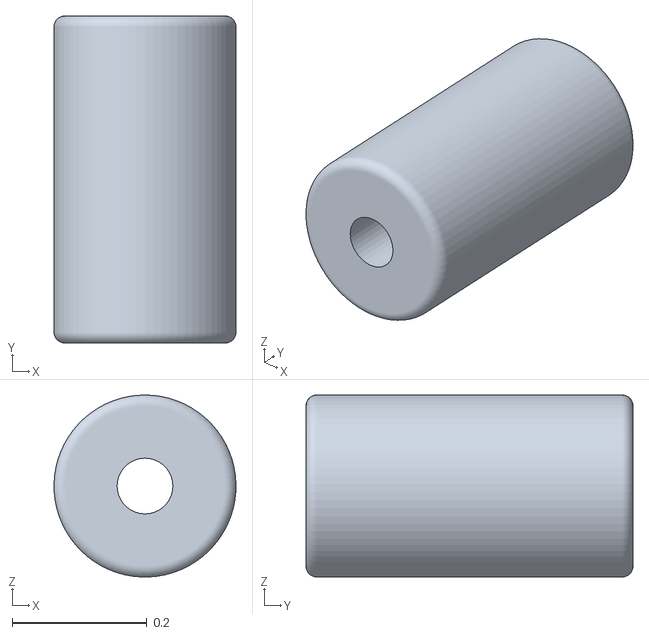
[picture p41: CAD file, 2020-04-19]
Design Materials/Mechanical/Pinch Valves/Cam Valve/STL/Roller Oversize.STL
0.27 x 0.485 x 0.27

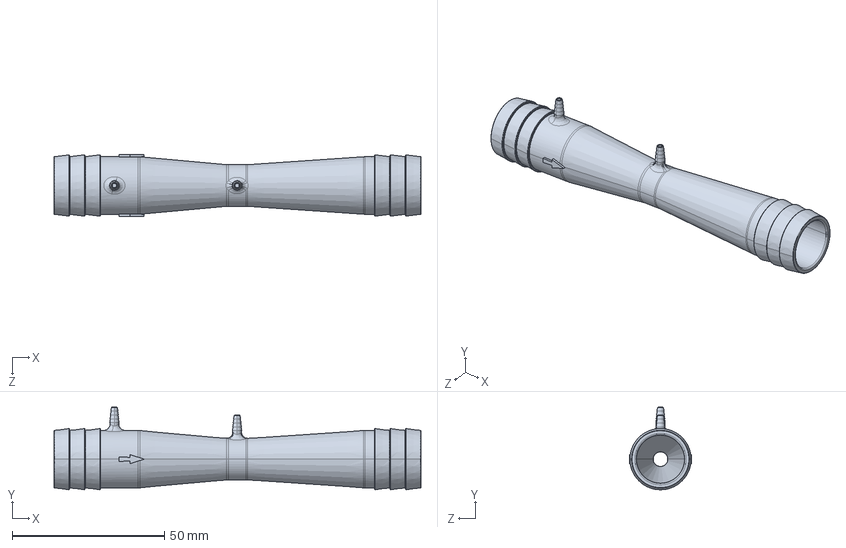
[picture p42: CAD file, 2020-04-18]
Design Materials/Mechanical/Venturi/BrunO2venturi.STEP
120.7 x 27.2 x 20.3 mm

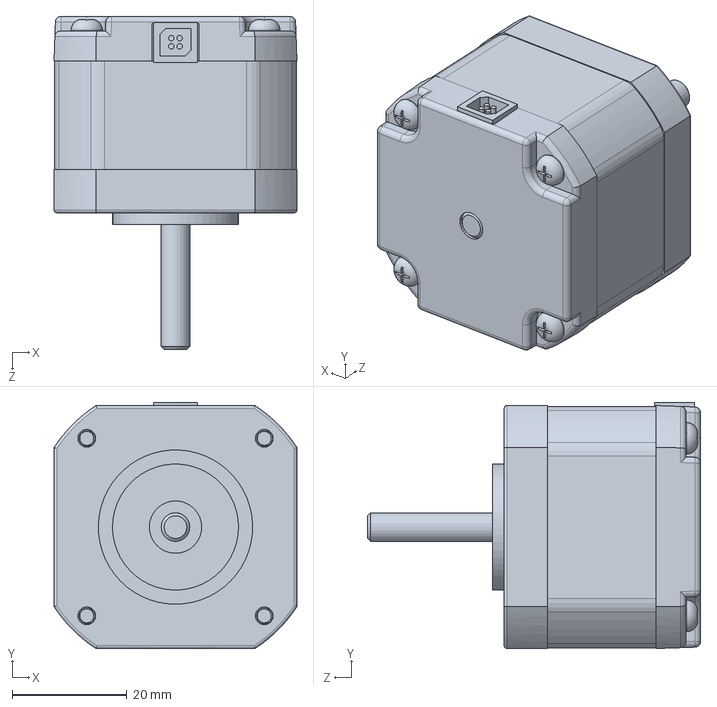
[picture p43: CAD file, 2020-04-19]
Design Materials/Mechanical/Pinch Valves/Cam Valve/SLDPRT/NEMA 17 Stepper.SLDPRT
42.4 x 43.0 x 58.2 mm

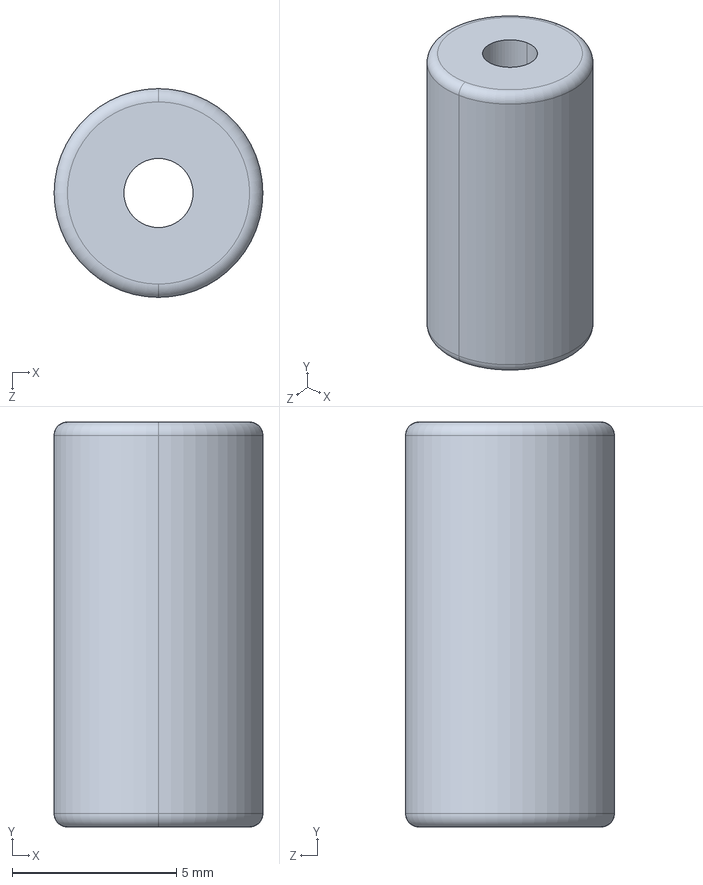
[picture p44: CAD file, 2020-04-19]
Design Materials/Mechanical/Pinch Valves/Cam Valve/STEP/Roller 0.375.STEP
6.35 x 12.3 x 6.35 mm

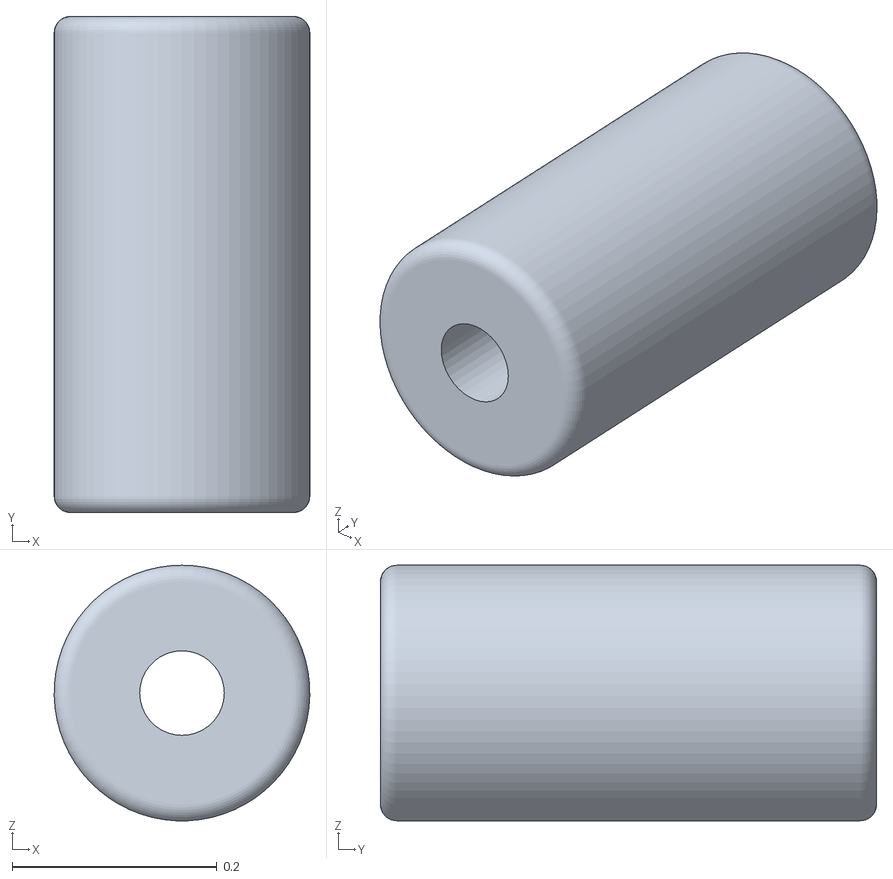
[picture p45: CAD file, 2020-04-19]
Design Materials/Mechanical/Pinch Valves/Cam Valve/STL/Roller.STL
0.25 x 0.485 x 0.25

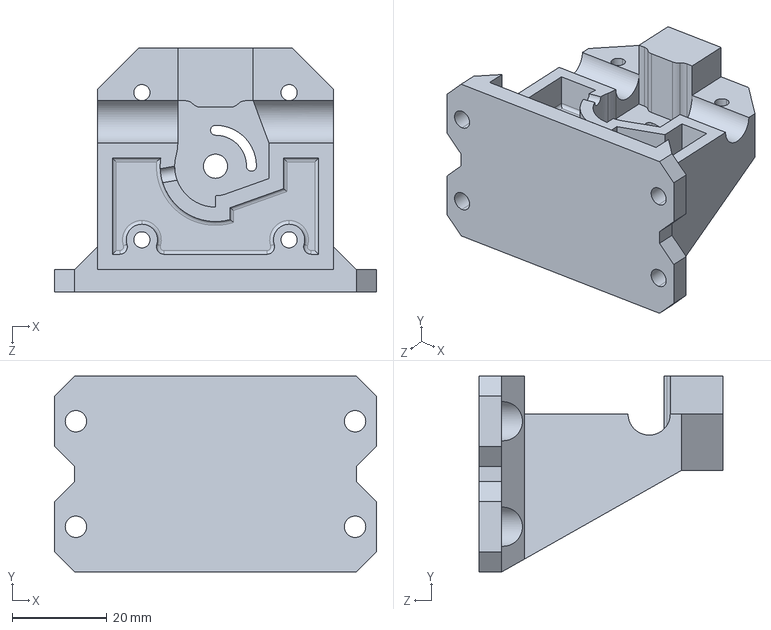
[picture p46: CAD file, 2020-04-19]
Design Materials/Mechanical/Pinch Valves/Cam Valve/STEP/Housing.STEP
67.8 x 41.3 x 51.4 mm

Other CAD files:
Design Materials/Mechanical/Pinch Valves/Cam Valve/STL/Roller Undersize.STL
Design Materials/Mechanical/Pinch Valves/Cam Valve/STEP/Top.STEP
Design Materials/Mechanical/Pinch Valves/Cam Valve/SLDPRT/0.375 Tubing.SLDPRT
Design Materials/Mechanical/Pinch Valves/Cam Valve/SLDPRT/M3x22 SHCP.SLDPRT
Design Materials/Mechanical/Adapters/1:4 NPT to 1:4-inch barb/1:4 NPT to 1:4-inch barb.f3d
Design Materials/Mechanical/Adapters/1:4 NPT to 1:4-inch barb/1:4 NPT to 1:4-inch barb.stl
Design Materials/Mechanical/Adapters/1:4 NPT to 3:4-inch barb/1:4 NPT to 3:4-inch barb.f3d
Design Materials/Mechanical/Adapters/1:4 NPT to 3:4-inch barb/1:4 NPT to 3:4-inch barb.stl
Design Materials/Mechanical/Adapters/3:4-inch barb to 1:4-inch barb/3:4-inch barb to 1:4-inch barb.f3d
Design Materials/Mechanical/Adapters/3:4-inch barb to 1:4-inch barb/3:4-inch barb to 1:4-inch barb.stl
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

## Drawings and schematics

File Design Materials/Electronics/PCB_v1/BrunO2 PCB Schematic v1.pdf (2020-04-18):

# 5V GND

# 3.3V GND

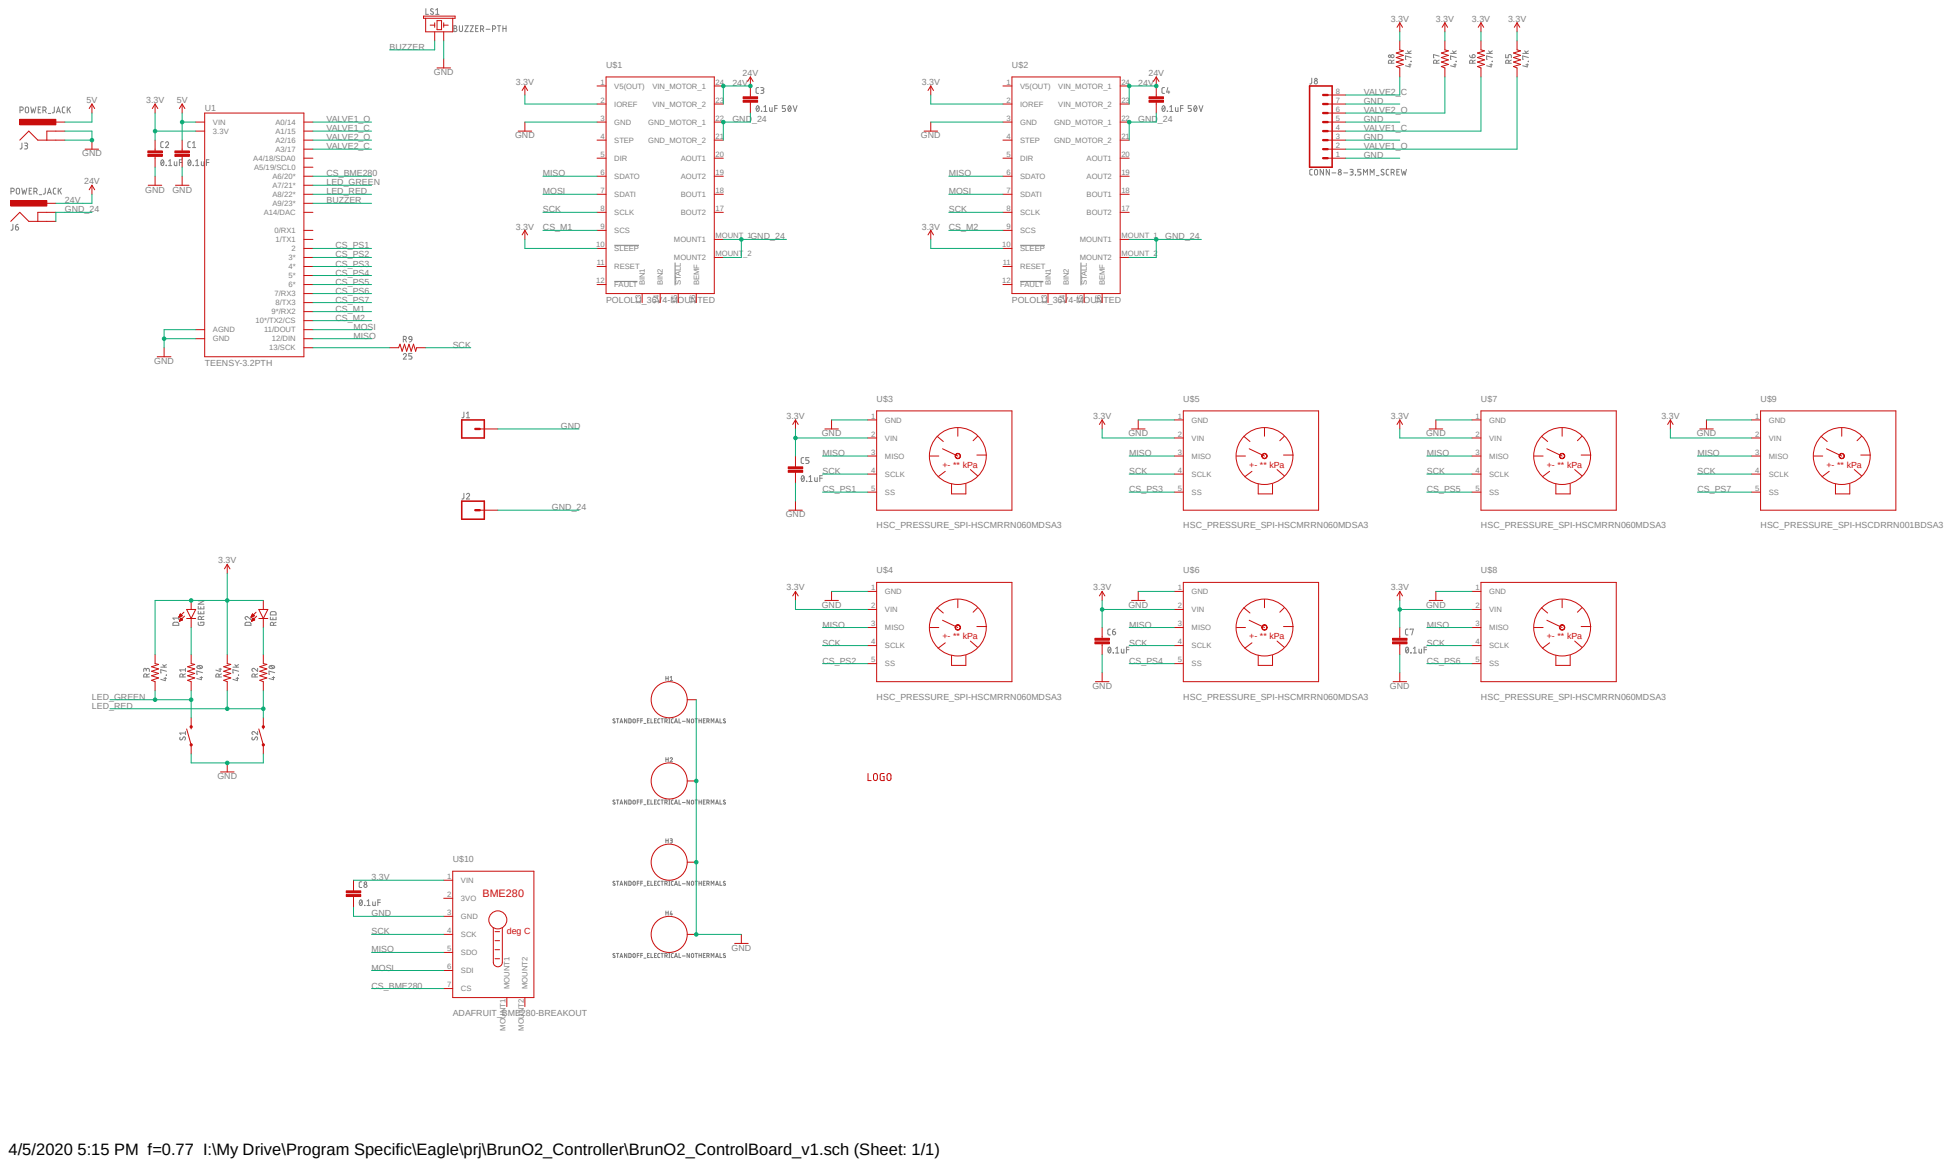
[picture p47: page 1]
TEENSY-3.2PTH; POLOLU_36V4-MOUNTED; GND; 3.3V GND; HSC_PRESSURE_SPI-HSCMRRN060MDSA3; HSC_PRESSURE_SPI-HSCDRRN001BDSA3 GND; GND GND; ADAFRUIT_BME280-BREAKOUT; 8/TX3 9*/RX2 10*/TX2/CS 11/DOUT 12/DIN 13/SCK; A0/14 A1/15 A2/16 A3/17 A4/18/SDA0 A5/19/SCL0 A6/20* A7/21* A8/22* A9/23* A14/DAC; AGND GND; VIN; IOREF 2; GND 3; SDATO 6; SDATI 7; SCLK 8; SCS 9; SLEEP 10; V5(OUT) 1; STEP 4; DIR 5; RESET 11; FAULT 12; BIN¹ 13; BIN² 14; STALL 15; BEMF 16 VIN_MOTOR_1; 24 VIN_MOTOR_2; 23 GND_MOTOR_1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

GND GND GND GND GND

4/5/2020 5:15 PM f=0.77 I:\My Drive\Program Specific\Eagle\prj\BrunO2_Controller\BrunO2_ControlBoard_v1.sch (Sheet: 1/1)

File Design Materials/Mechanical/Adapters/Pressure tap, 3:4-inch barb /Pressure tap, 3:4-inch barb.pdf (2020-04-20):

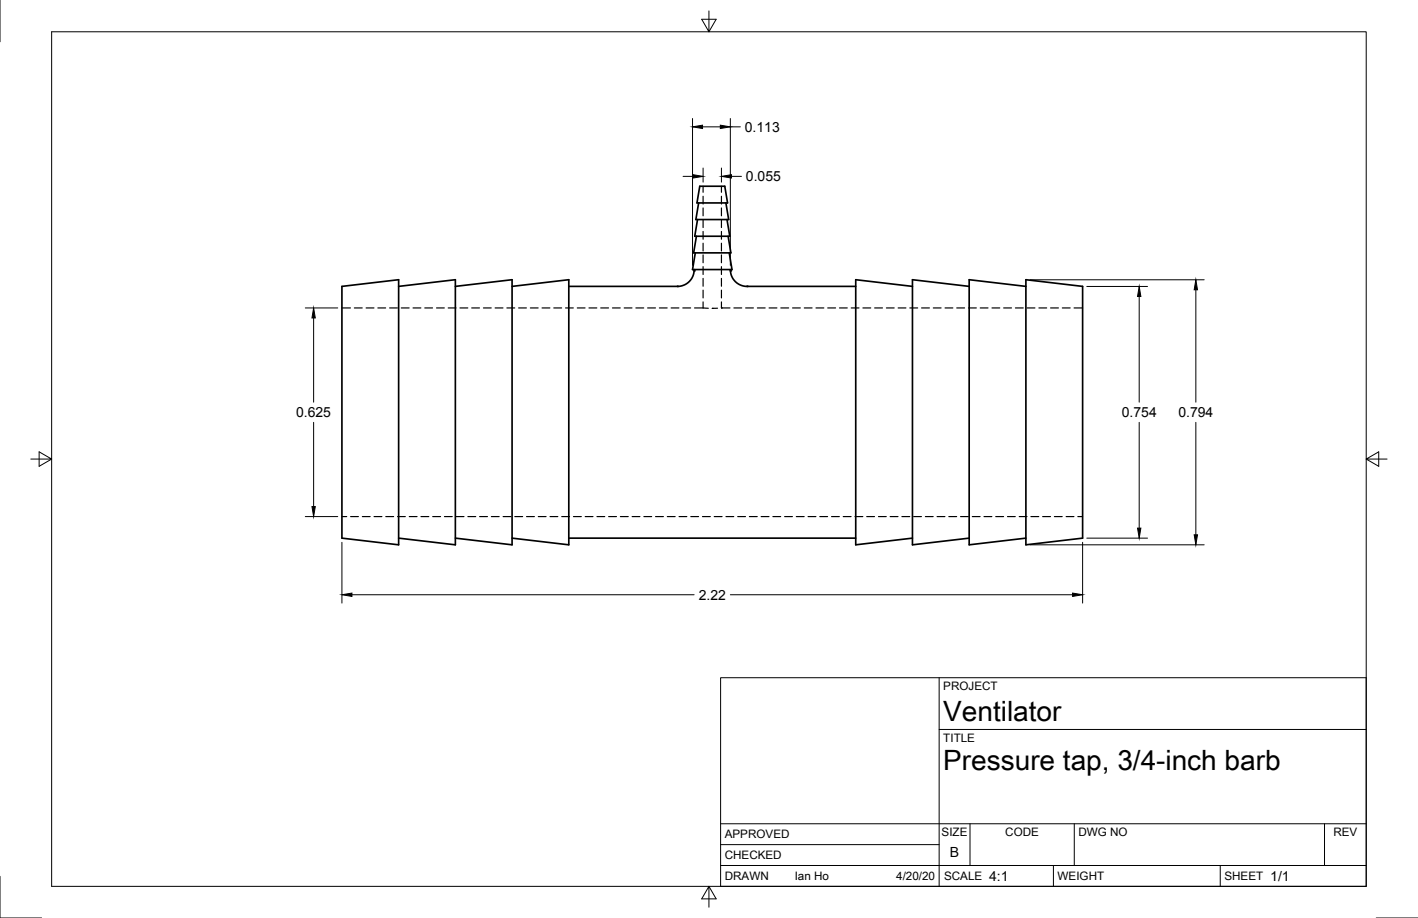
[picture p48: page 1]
SIZE; CODE; DWG NO; REV; Ian Ho

PROJECT
Ventilator
Pressure tap, 3/4-inch barb

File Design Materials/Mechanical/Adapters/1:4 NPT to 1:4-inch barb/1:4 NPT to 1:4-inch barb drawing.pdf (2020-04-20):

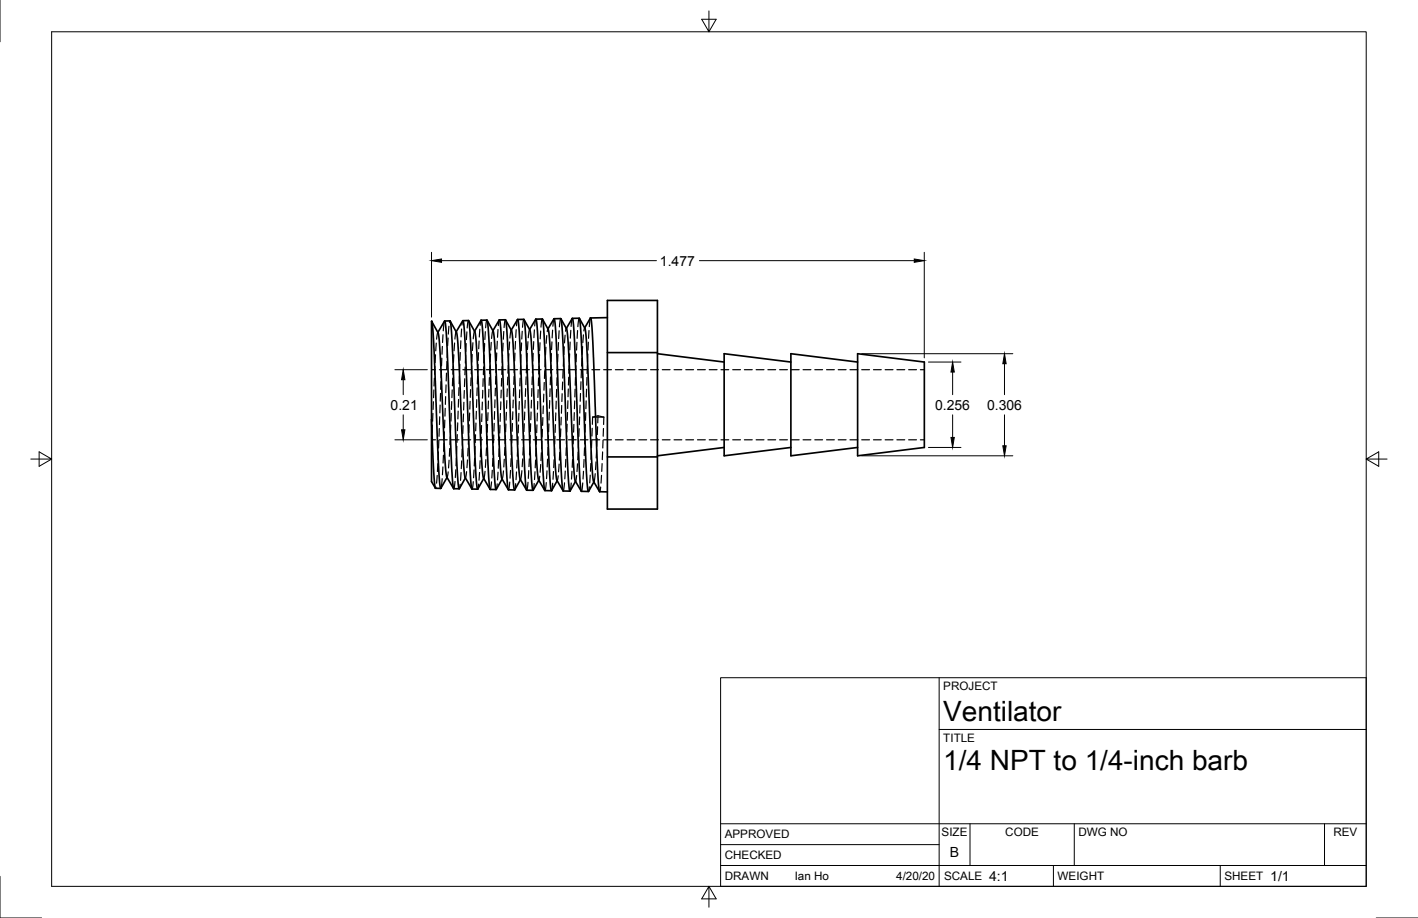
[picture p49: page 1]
SIZE; CODE; DWG NO; REV; Ian Ho

PROJECT
Ventilator
1/4 NPT to 1/4-inch barb

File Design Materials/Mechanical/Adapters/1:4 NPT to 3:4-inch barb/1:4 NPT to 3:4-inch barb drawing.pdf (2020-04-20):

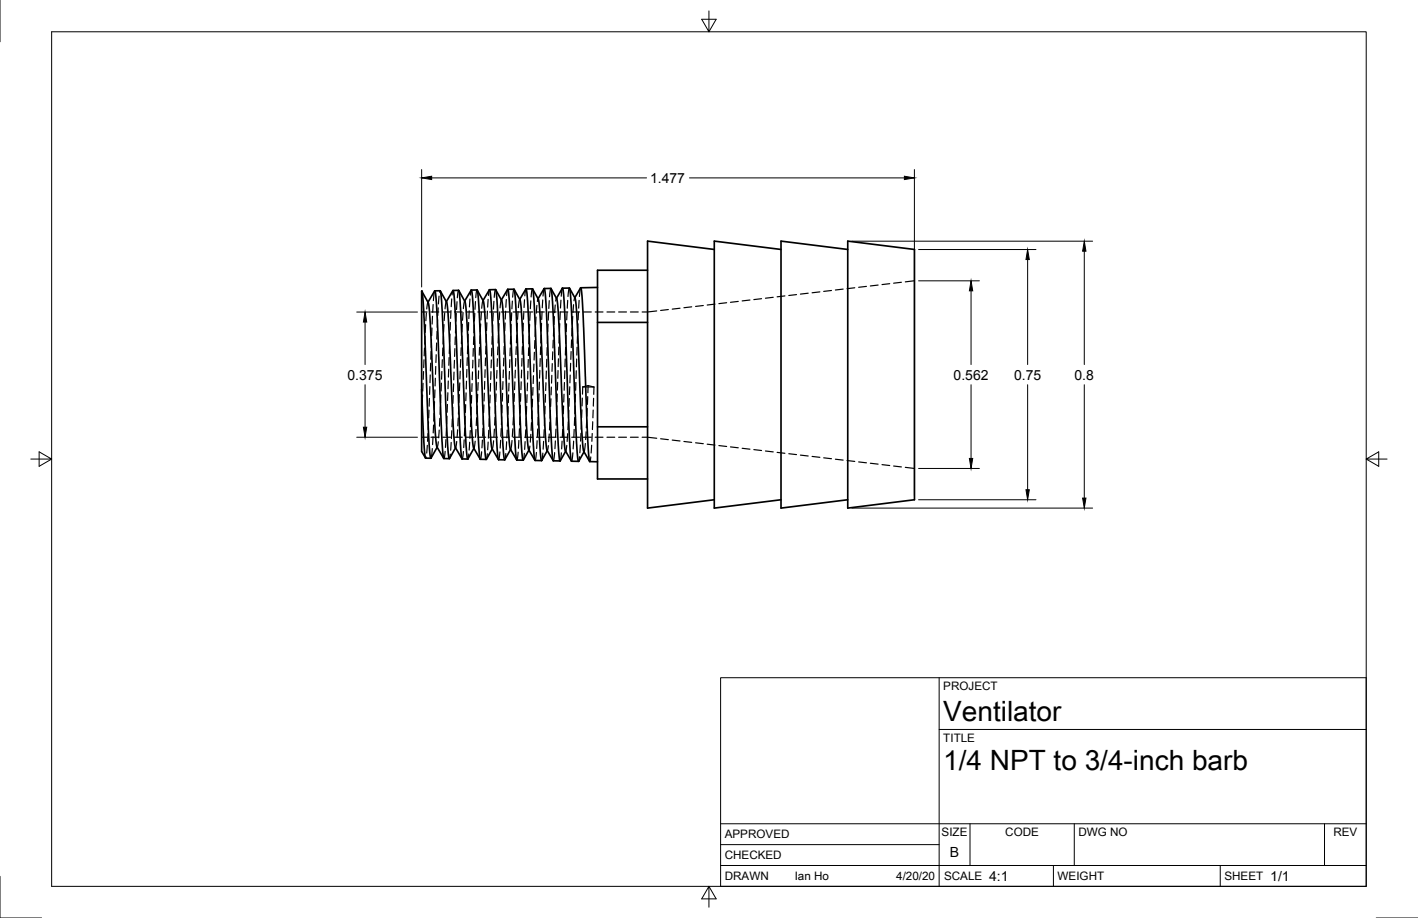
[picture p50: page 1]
SIZE; CODE; DWG NO; REV; Ian Ho

PROJECT
Ventilator
1/4 NPT to 3/4-inch barb

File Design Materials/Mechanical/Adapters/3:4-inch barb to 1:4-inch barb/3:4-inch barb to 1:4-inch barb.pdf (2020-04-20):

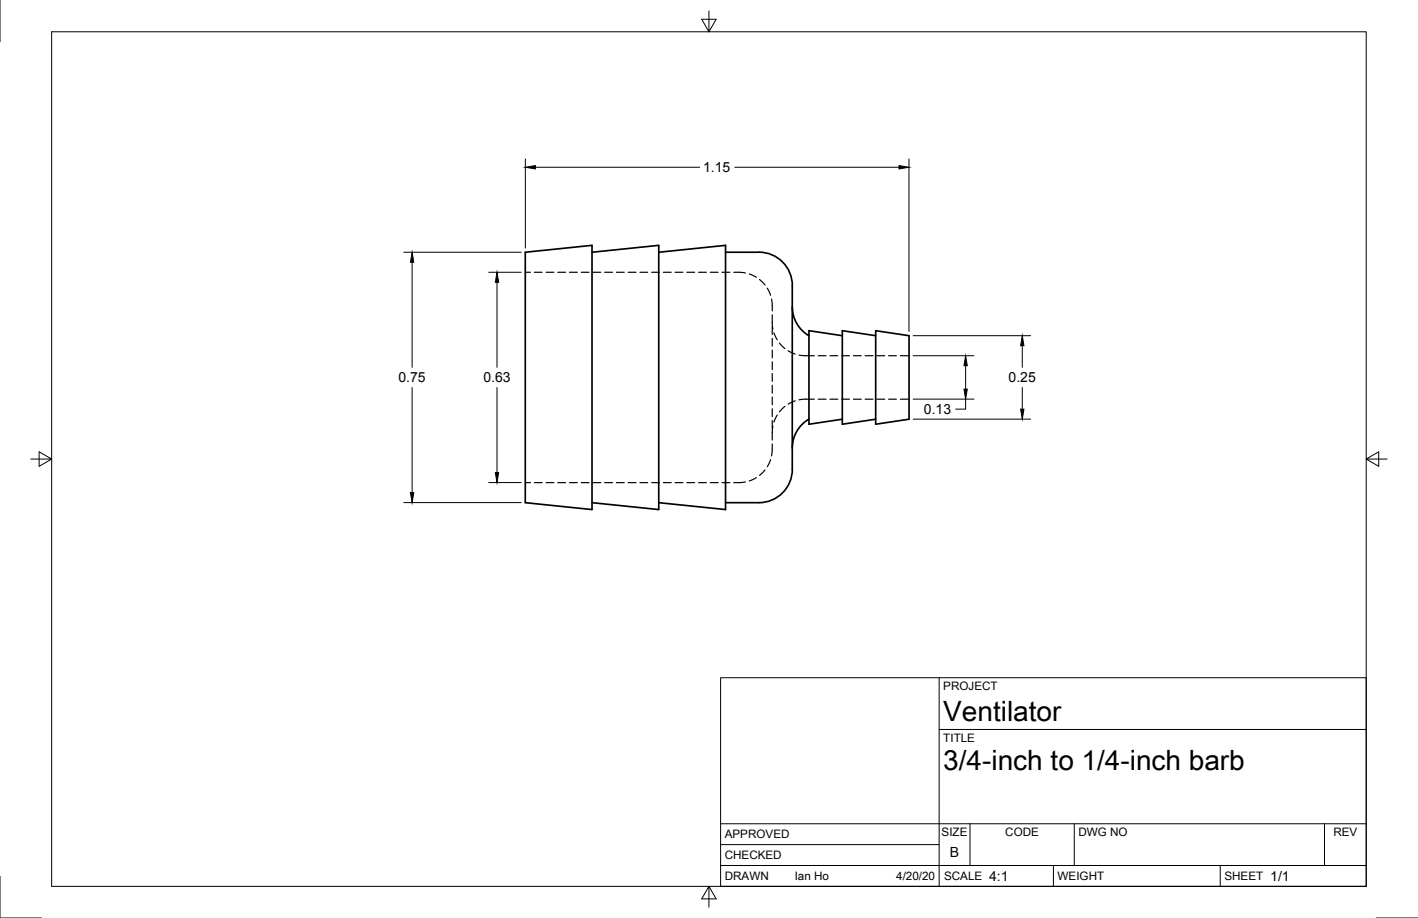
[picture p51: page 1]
SIZE; CODE; DWG NO; REV; Ian Ho

PROJECT
Ventilator
3/4-inch to 1/4-inch barb

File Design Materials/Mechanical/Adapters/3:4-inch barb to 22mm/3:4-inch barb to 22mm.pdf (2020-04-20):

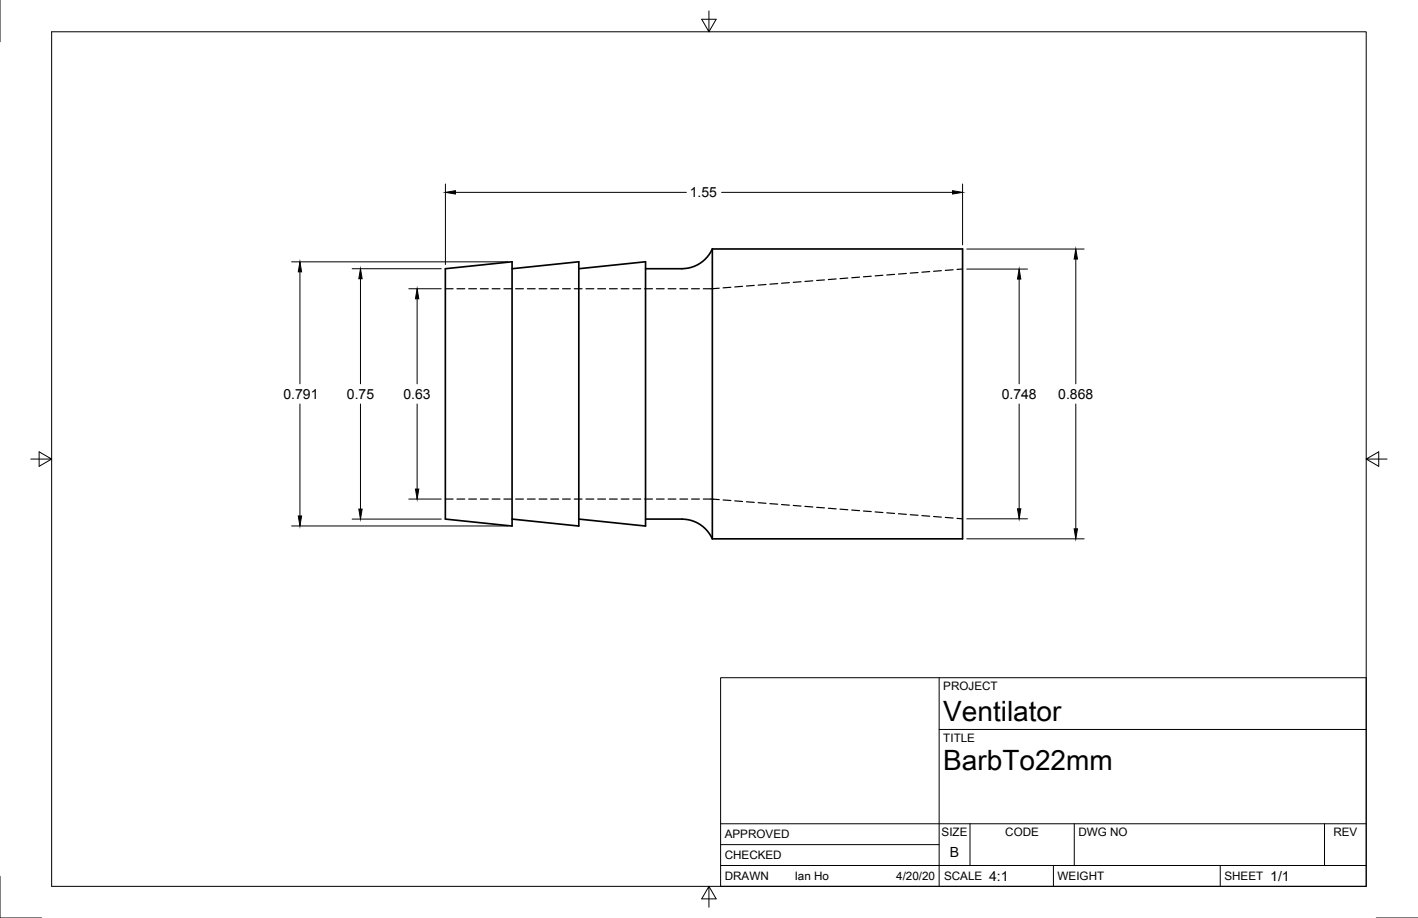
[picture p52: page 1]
SIZE; CODE; DWG NO; REV; Ian Ho

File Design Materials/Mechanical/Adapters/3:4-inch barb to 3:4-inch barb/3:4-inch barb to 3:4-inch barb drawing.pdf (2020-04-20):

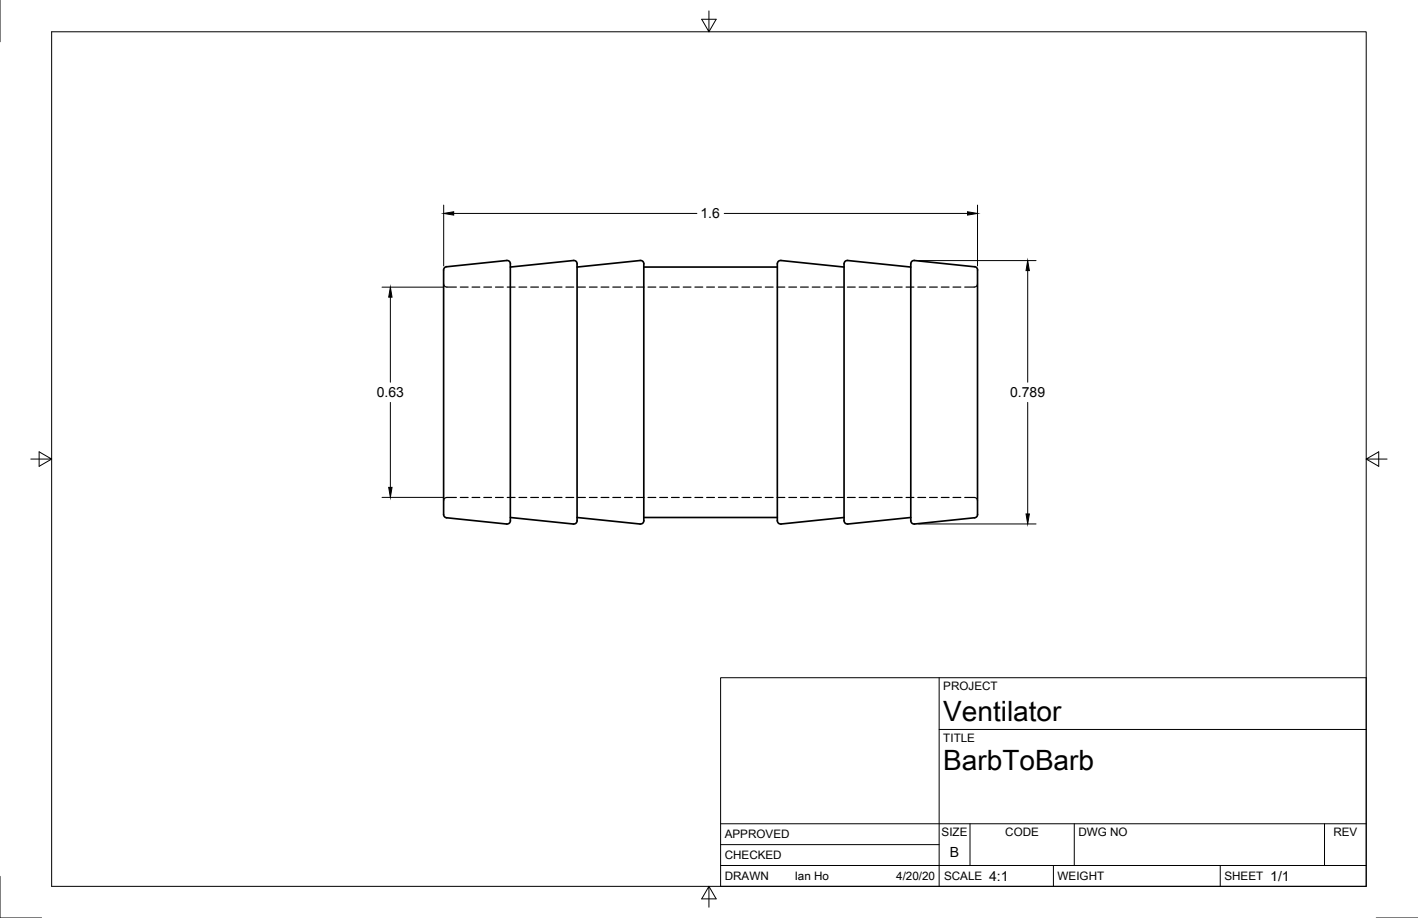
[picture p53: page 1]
SIZE; CODE; DWG NO; REV; Ian Ho

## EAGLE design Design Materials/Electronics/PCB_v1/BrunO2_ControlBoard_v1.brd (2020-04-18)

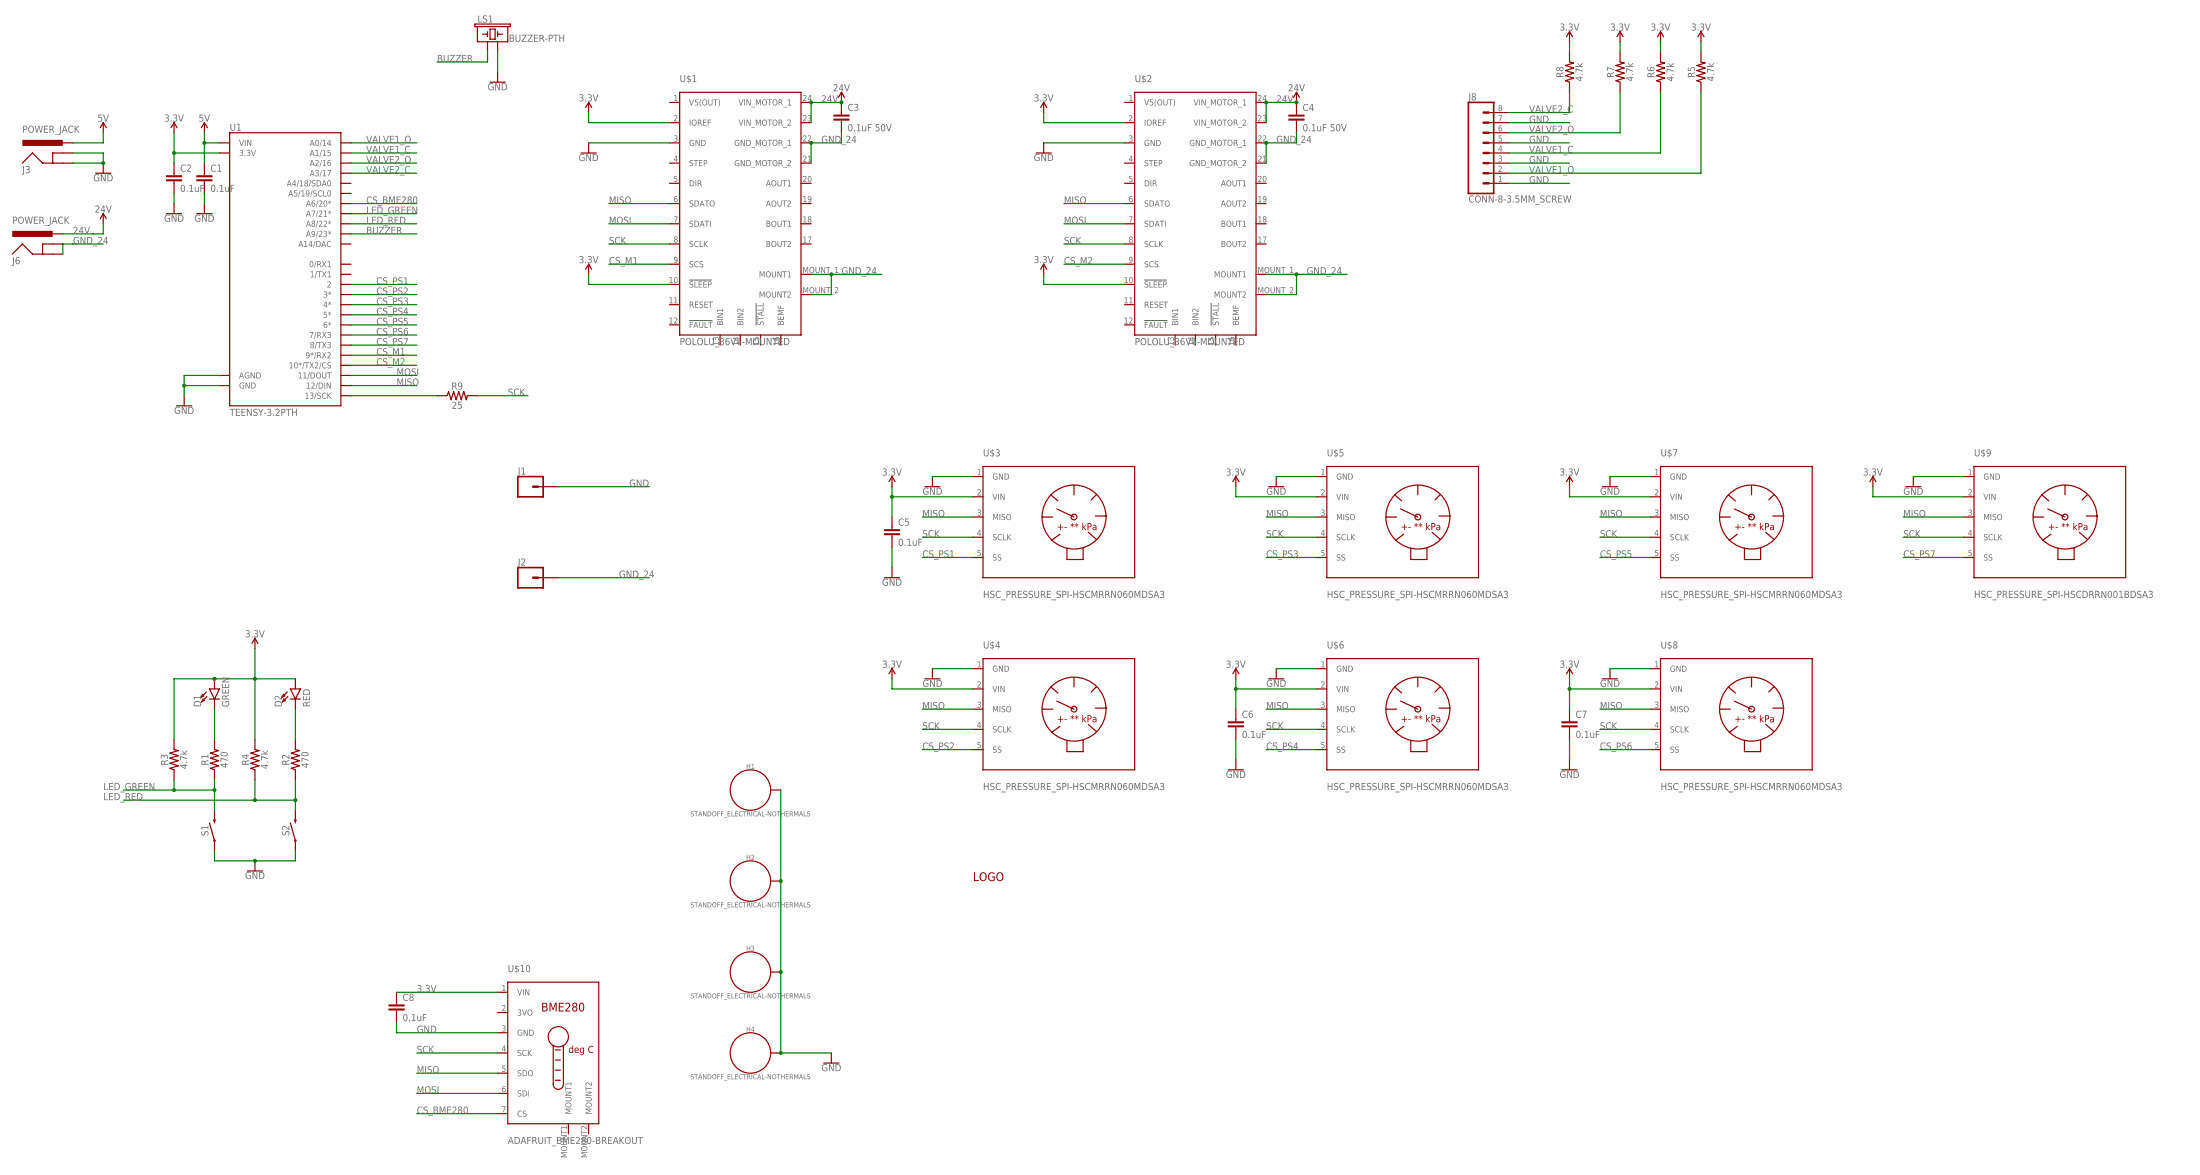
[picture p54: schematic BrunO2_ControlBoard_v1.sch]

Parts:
C1, C2, C5, C6, C7, C8: 0.1uF; CAP-PTH-SMALL-KIT
C3, C4: 0.1uF 50V; CAP-PTH-SMALL-KIT
D1: GREEN; LED_5MM-KIT-NO-SILK
D2: RED; LED_5MM-KIT-NO-SILK
H1, H2, H3, H4: STANDOFF_ELECTRICAL-NOTHERMALS; STANDOFF-ELECTRICAL-NOTHERMALS
J1, J2: CONN_01; 1X01
J3, J6: POWER_JACK; POWER_JACK_PTH
J8: CONN-8-3.5MM_SCREW; SCREWTERMINAL-3.5MM-8
LS1: BUZZER-PTH; BUZZER-12MM
R1, R2: 470; AXIAL-0.3
R3, R4, R5, R6, R7, R8: 4.7k; AXIAL-0.3
R9: 25; AXIAL-0.3
S1, S2: MOMENTARY-SWITCH-SPST-PTH-6.0MM; TACTILE_SWITCH_PTH_6.0MM
U1: TEENSY-3.2PTH; TEENSY_TEENSY-3.2-PTH
U$1, U$2: POLOLU_36V4-MOUNTED; POLOLU_36V4
U$3, U$4, U$5, U$6, U$7, U$8: HSC_PRESSURE_SPI-HSCMRRN060MDSA3; HSC_PRESSURE_DIP
U$9: HSC_PRESSURE_SPI-HSCDRRN001BDSA3; HSC_PRESSURE_DIP
U$10: ADAFRUIT_BME280-BREAKOUT; ADAFRUIT_BME280
U$11: LOGO-BRUNO2; BRUNO2_LOGO

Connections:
3.3V: C2.1, C5.1, C6.1, C7.1, C8.1, D1.A, D2.A, R3.P$2 (2), R4.P$2 (2), R5.P$2 (2), R6.P$2 (2), R7.P$2 (2), R8.P$2 (2), U1.3.3V, U1.3.3V-1 (3.3V), U$1.2 (IOREF), U$1.10 (!SLEEP), U$2.2 (IOREF), U$2.10 (!SLEEP), U$3.2 (VIN), U$4.2 (VIN), U$5.2 (VIN), U$6.2 (VIN), U$7.2 (VIN), U$8.2 (VIN), U$9.2 (VIN), U$10.1 (VIN)
5V: C1.1, J3.PWR, U1.VIN
24V: C3.1, C4.1, J6.PWR, U$1.23 (VIN_MOTOR_2), U$1.24 (VIN_MOTOR_1), U$2.23 (VIN_MOTOR_2), U$2.24 (VIN_MOTOR_1)
BUZZER: LS1.+ (1), U1.23 (A9/23*)
CS_BME280: U1.20 (A6/20*), U$10.7 (CS)
CS_M1: U1.9 (9*/RX2), U$1.9 (SCS)
CS_M2: U1.10 (10*/TX2/CS), U$2.9 (SCS)
CS_PS1: U1.2, U$3.5 (SS)
CS_PS2: U1.3 (3*), U$4.5 (SS)
CS_PS3: U1.4 (4*), U$5.5 (SS)
CS_PS4: U1.5 (5*), U$6.5 (SS)
CS_PS5: U1.6 (6*), U$7.5 (SS)
CS_PS6: U1.7 (7/RX3), U$8.5 (SS)
CS_PS7: U1.8 (8/TX3), U$9.5 (SS)
GND: C1.2, C2.2, C5.2, C6.2, C7.2, C8.2, H1.P1, H2.P1, H3.P1, H4.P1, J1.1, J3.GND, J3.GNDBREAK, J8.1, J8.3, J8.5, J8.7, LS1.- (2), S1.1, S2.1, U1.AGND, U1.GND, U1.GND1 (GND), U$1.3 (GND), U$2.3 (GND), U$3.1 (GND), U$4.1 (GND), U$5.1 (GND), U$6.1 (GND), U$7.1 (GND), U$8.1 (GND), U$9.1 (GND), U$10.3 (GND)
GND_24: C3.2, C4.2, J2.1, J6.GND, J6.GNDBREAK, U$1.21 (GND_MOTOR_2), U$1.22 (GND_MOTOR_1), U$1.MOUNT_1 (MOUNT1), U$1.MOUNT_2 (MOUNT2), U$2.21 (GND_MOTOR_2), U$2.22 (GND_MOTOR_1), U$2.MOUNT_1 (MOUNT1), U$2.MOUNT_2 (MOUNT2)
LED_GREEN: R1.P$1 (1), R3.P$1 (1), S1.3 (2), U1.21 (A7/21*)
LED_RED: R2.P$1 (1), R4.P$1 (1), S2.3 (2), U1.22 (A8/22*)
MISO: U1.12 (12/DIN), U$1.6 (SDATO), U$2.6 (SDATO), U$3.3 (MISO), U$4.3 (MISO), U$5.3 (MISO), U$6.3 (MISO), U$7.3 (MISO), U$8.3 (MISO), U$9.3 (MISO), U$10.5 (SDO)
MOSI: U1.11 (11/DOUT), U$1.7 (SDATI), U$2.7 (SDATI), U$10.6 (SDI)
unnamed: D1.K (C), R1.P$2 (2)
unnamed: R9.P$1 (1), U1.13 (13/SCK)
unnamed: D2.K (C), R2.P$2 (2)
SCK: R9.P$2 (2), U$1.8 (SCLK), U$2.8 (SCLK), U$3.4 (SCLK), U$4.4 (SCLK), U$5.4 (SCLK), U$6.4 (SCLK), U$7.4 (SCLK), U$8.4 (SCLK), U$9.4 (SCLK), U$10.4 (SCK)
VALVE1_C: J8.4, R6.P$1 (1), U1.15 (A1/15)
VALVE1_O: J8.2, R5.P$1 (1), U1.14 (A0/14)
VALVE2_C: J8.8, R8.P$1 (1), U1.17 (A3/17)
VALVE2_O: J8.6, R7.P$1 (1), U1.16 (A2/16)

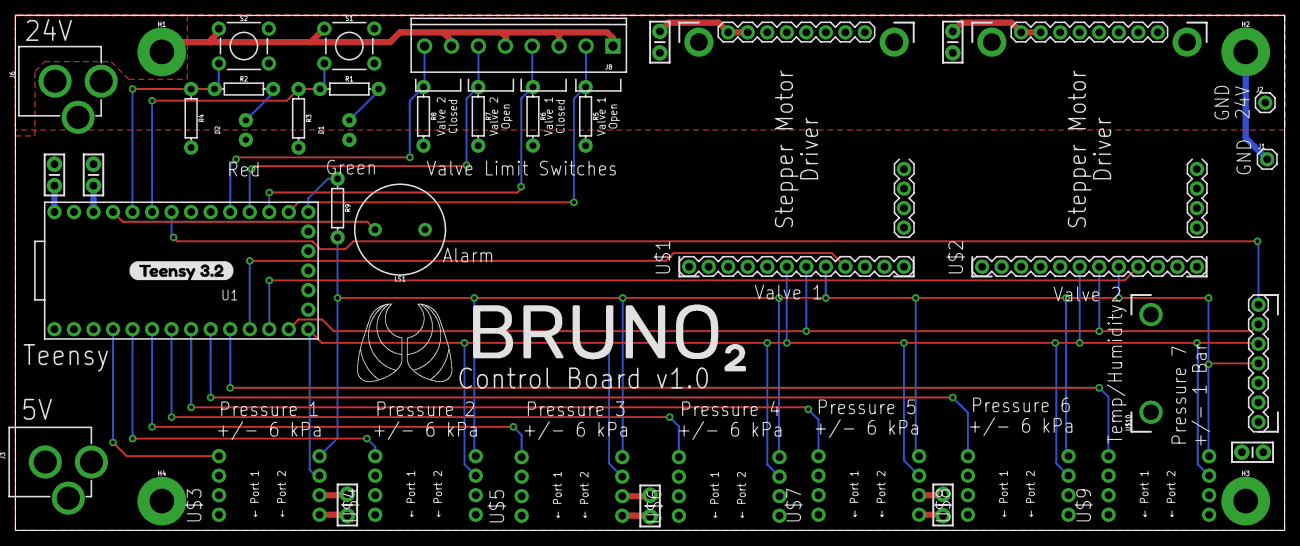
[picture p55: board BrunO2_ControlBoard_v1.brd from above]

Board: 2 copper layers, 165.1 x 67.0 mm, 43 parts (0 on the bottom side), 28 nets.

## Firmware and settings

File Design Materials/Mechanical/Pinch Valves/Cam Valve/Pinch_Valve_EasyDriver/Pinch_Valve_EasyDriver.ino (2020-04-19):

//Sample code for controlling cam valve over computer serial with a Schamlzhaus EasyDriver and Arduino


//Declare pin functions on Redboard
#define stp 3
#define dir 2
#define MS1 4
#define MS2 5
#define EN  6

//Declare variables for functions
char user_input;
String inputStr;
int curPos;
int posDifference;
long delayVal = 5000; //microseconds delay between toggling step pin
int i; //for loops
int input;

bool turnDir = true; //Change this if the direction is wrong

void setup() {
  pinMode(stp, OUTPUT);
  pinMode(dir, OUTPUT);
  pinMode(MS1, OUTPUT);
  pinMode(MS2, OUTPUT);
  pinMode(EN, OUTPUT);
  pinMode(Trigger, OUTPUT);
  resetEDPins(); //Set step, direction, microstep and enable pins to default states
  Serial.begin(9600); //Open Serial connection for debugging
  Serial.println("Begin motor control");
  Serial.println();
  //Print function list for user selection
  Serial.println("Enter a position between 0 - 100 (0 = closed):");
  Serial.println("Press H to home the stepper");
  Serial.println();

  digitalWrite(MS1, HIGH); //Pull MS1 high and MS2 high to set logic to 1/8 microstep resolution
  digitalWrite(MS2, HIGH);
  digitalWrite(EN, LOW); //enable the stepper motor
}

//Main loop
void loop() {
  while(Serial.available()){
      user_input = Serial.read(); //Read user input and trigger appropriate function
      if (user_input =='H')
      {
         Home();
      }
      else if(user_input >= 48 && user_input <= 57)
      {
        inputStr += user_input;
        delay(2);
        while (Serial.available()){
        user_input = Serial.read();  //gets one byte from serial buffer
        inputStr += user_input; //makes the string readString
        delay(2);  //slow looping to allow buffer to fill with next character
        //Serial.println("number read");
        }
        input = inputStr.toInt();
        MoveToPos(input);
        inputStr = "";
      }
      else
      {
        Serial.println("Invalid option entered.");
      }
      //resetEDPins();
  }
}

//Reset Easy Driver pins to default states
void resetEDPins()
{
  digitalWrite(stp, LOW);
  digitalWrite(dir, LOW);
  digitalWrite(MS1, LOW);
  digitalWrite(MS2, LOW);
  digitalWrite(EN, LOW);
}

//Home the valve by running against a hard stop
//dir LOW to move clockwise
void Home()
{
  Serial.println("Homing...");
  digitalWrite(dir, turnDir); //homing in the counterclockwise direction
  for(i = 1; i<400; i++)  //loop enough to move a quarter rotation at 1/8 microstepping
  {
    digitalWrite(stp,HIGH); //Trigger one step forward
    delay(1);
    digitalWrite(stp,LOW); //Pull step pin low so it can be triggered again
    delay(1);
    curPos = 0;
  }
  Serial.println("Homing complete");
}

//move to the set position
//range is quarter circle split into 100 increments
int MoveToPos(int setPos) {
  
  if (setPos > 100) {
    setPos = 100;
  }

  if (setPos < 0) {
    setPos = 0;
  }
  
  if (setPos > curPos) {
    //move clockwise
    digitalWrite(dir, !turnDir);
    posDifference = setPos - curPos;
    for (i = 0; i < 4*posDifference; i++) {
      digitalWrite(stp,HIGH); //Trigger one step forward
      delayMicroseconds(delayVal);
      digitalWrite(stp,LOW); //Pull step pin low so it can be triggered again
      delayMicroseconds(delayVal);
    }
    
  }
  if (setPos < curPos) {
    //move counterclockwise
    digitalWrite(dir, turnDir);
    posDifference = curPos - setPos;
    for (i = 0; i < 4*posDifference; i++) {
      digitalWrite(stp,HIGH); //Trigger one step forward
      delayMicroseconds(delayVal);
      digitalWrite(stp,LOW); //Pull step pin low so it can be triggered again
      delayMicroseconds(delayVal);
    }
  }
  curPos = setPos;
}

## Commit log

2020-03-29 All messages between Pi + Teensy should work; however they are not acknowledged.
2020-03-29 C:/Program Files/Git/c, /s, /p, /m messages are all handled/sent. /e,/c,/b are ignored. Recieved messages are acknowledged, but no acknowledgements are expected on sent messages. main_basic.py now ta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
2020-04-05 removing submodule, arduino includes sucks
2020-04-18 PCB files
    [BrunO2_ControlBoard_v1.brd, BrunO2_ControlBoard_v1.sch]
2020-04-18 add venturi design
    [BrunO2venturi.SLDPRT, BrunO2venturi.STEP, BrunO2venturi.STL]
2020-04-19 Adding teensy pin assigments and images of top and bottom of pcb
    [TeensyPinAssignment.xlsx]
2020-04-19 added valve design materials
    [0.375 Tubing.SLDPRT, Cam.SLDPRT, Cam.STEP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]

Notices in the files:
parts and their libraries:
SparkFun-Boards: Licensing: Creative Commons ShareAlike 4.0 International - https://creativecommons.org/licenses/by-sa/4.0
